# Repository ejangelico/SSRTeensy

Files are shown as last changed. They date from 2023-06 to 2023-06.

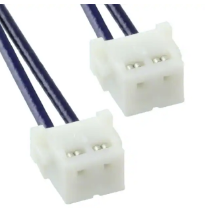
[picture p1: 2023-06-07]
widaq-magis-ssr-v2b/v2a-power-board/box-assembly/Screenshot 2023-04-20 at 11.49.00 AM.png

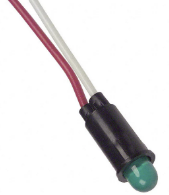
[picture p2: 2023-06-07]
widaq-magis-ssr-v2b/v2a-power-board/box-assembly/Screenshot 2023-04-20 at 11.48.34 AM.png

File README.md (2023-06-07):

# SSRTeensy

## Libraries
Arduino 1.8.15
Teensydino 1.54

# Communication interface guide (documentation in progress)

There are 16 pulse width modulation (PWM) channels active and available for functions related to setting the temperature of heaters using solid state relays and thermocouple feedback. Each of the channels initializes an "SSRController" object. The object contains a state enumerator for the presently active function of the channel. This section describes how to interface with each channel by sending messages over a serial connection. 

### Available commands

The general structure of a message to the Teensy is in the following form: `#<ch>:<command>=<arg1>,<arg2>,<arg3>,<arg4>,<arg5>` . 

Depending on the command type, there may be a different number of required arguments, and argument parsing stops once the required arguments are parsed. Commands are their arguments are described in the below list. 

- TEMP_SET : command subset for changing the SSR duty cycles to match a setpoint temperature or manual input
    - POWER_OFF : turn SSR relays to 0 duty cycle
        - `#3:TEMP_SET=POWER_OFF,,,`
    - RAMP : linear ramp in temperature up to a setpoint
    - CONST : reach a constant temperature (with no controlled slope ramp) and hold at that temperature
    - MANUAL : manually set the duty cycle of SSRs to some fraction from 0% to 100%
        - `#3:TEMP_SET=MANUAL,<duty cycle 0 to 100>,,,`, `#3:TEMP_SET=MANUAL,43.5,,,`
- TEMP_CUR : provide the Teenys with information about the present temperature associated with a particular SSR channel; this is feedback for a PID loop or any of the TEMP_SET functions
    - `#<ch>:TEMP_CUR=<temp in C>,<timestamp>`, `#3:TEMP_CUR=32.5,1656444270`
- PIDP_SET : set the P, I, and D parameters for the PID control equation

# To do for devs
- We want to change the ramp functionality inputs so that the UI just presses "start" or "stop" and the linear ramp curve is executed automatically (no timing arguments). Target temp and ramp rate are still args, but even ramp rate can have a default of 1 C/min.

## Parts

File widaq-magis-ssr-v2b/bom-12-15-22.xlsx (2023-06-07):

ID | # per board | spare per board | cost per part | number of boards | total required | total cost | component label | component type | value | vendor | product number | link | Note | Checked for correctness
1 | 4 | 0 | 19.95 | 6 | 24 | 478.8 | Teen1 | Teensy 4.0 | Teensy4 | SparkFun | DEV-16771 | here (https://www.pjrc.com/store/teensy40.html)
2 | 8 | 0 | 0.82 | 6 | 48 | 39.36 | Teen1-sockets | 14 Pin female header |  | Digikey | S7012-ND | here | soldered to pcb
3 | 16 | 2 | 0.44 | 6 | 108 | 47.52 | BUF_0-3, BUF_4-7, BUF_8-11, BUF_12-15 | IC buffer 5.5 14-DIP package | SN74AHCT125 | Digikey | 296-4655-5-ND | here (https://www.digikey.com/en/products/detail/texas-instruments/sn74ahct125n/375798)
4 | 16 | 0 | 0.21 | 6 | 96 | 20.16 | BUF_0-3, BUF_4-7, BUF_8-11, BUF_12-15 | Socket for 14-DIP IC | A14-LC-TT | Digikey | AE9989-ND | here (https://www.digikey.com/en/products/detail/assmann-wsw-components/a-14-lc-tt/821743)
5 | 5 | 1 | 3.24 | 3 | 18 |  |  | Panel mount LEDs, built in resistor |  | Digikey |  | here (https://www.digikey.com/en/products/detail/visual-communications-company---vcc/5102H5-5V/59913)
6 | 2 | 1 | 0.09 | 6 | 18 | 1.62 | R3,R4 | Resistor | 10k | Digikey | CF18JT10K0CT-ND | here (https://www.digikey.com/en/products/detail/stackpole-electronics-inc/CF18JT10K0/1741566)
7 | 1 | 1 | 0.09 | 6 | 12 | 1.08 | R1 | Resistor | 1k | Digikey | CF14JT1K00CT-ND | here (https://www.digikey.com/product-detail/en/stackpole-electronics-inc/CF14JT1K00/CF14JT1K00CT-ND/1830350)
8 | 1 | 1 | 0.09 | 6 | 12 | 1.08 | R2 | Resistor | 2k | Digikey | CF14JT2K00CT-ND | here (https://www.digikey.com/product-detail/en/stackpole-electronics-inc/CF14JT2K00/CF14JT2K00CT-ND/1830357)
9 | 2 |  |  | 3 | 6 |  |  | Switches for front panel |  | Digikey |  | here (https://www.digikey.com/en/products/detail/zf-electronics/SRB22A2FBBNN/446021)
10 | 1 |  |  | 3 | 3 |  |  | Button for front panel |  | Digikey |  | here (https://www.digikey.com/en/products/detail/switchcraft-inc./903X/1832324)
11 | 4 | 0 | 3.81 | 6 | 24 |  |  | Ribbon cable PCB receptacle, 34 pin |  | Digikey | A33169-ND | here (https://www.digikey.com/en/products/detail/te-connectivity-amp-connectors/5103309-7/1114907)
12 | 4 | 1 | 2.75 | 6 | 30 |  |  | Ribbon cable connector, free 34 pin |  | Digikey | ASC34H-ND | here (https://www.digikey.com/en/products/detail/te-connectivity-amp-connectors/1658620-8/825431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)
13 | 4 | 0 |  | 6 | 24 |  |  | DSUB-37 to ribbon |  | Digikey | HMU37H-ND | here (https://www.digikey.com/en/products/detail/assmann-wsw-components/A-DSF-37LPIII-Z-UNC/924313)
14 | 4 | 1 | 0.85 | 3 | 15 |  |  | USB-C jack |  | Digikey | 2169900003 | here (https://www.digikey.com/en/products/detail/molex/2169900003/13913753)
15 | 1 | 1 | 2 | 3 | 6 |  |  | Ribbon connection cable between RPi and Power board |  | Adafruit | 370 | here (https://www.adafruit.com/product/370)
16 | 1 | 1 | 0.21 | 3 | 6 |  |  | 2x5 pin header soldered in power board |  | Digikey |  | here (https://www.digikey.com/en/products/detail/adam-tech/PH2-12-UA/9830397)
17 | 4 | 1 | 0.16 | 3 | 15 |  |  | 2-pin JST header for LED cable |  | Digikey |  | here (https://www.digikey.com/en/products/detail/jst-sales-america-inc./S2B-PH-K-SLFSN/926626)
18 | 4 | 1 | 1.07 | 3 | 15 |  |  | 2-pin cable for LEDs |  | Digikey |  | here (https://www.digikey.com/en/products/detail/jst-sales-america-inc/A02KR02KR26E305B/6194809)
 |  |  |  |  | Cost per board | Overall total
 |  |  |  |  | 98.27 | 589.62
 |  |  |  |  |  |  |  | Please order, as of 12-15-2022, where BOM is still in progress

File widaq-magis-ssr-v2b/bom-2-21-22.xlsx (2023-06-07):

ID | # per board | spare per board | cost per part | number of boards | total required | total cost | component label | component type | value | vendor | product number | link | Note | Checked for correctness
1 | 1 | 0 | 19.95 | 2 | 2 | 39.9 | Teen1 | Teensy 4.0 | Teensy4 | SparkFun | DEV-16771 | here (https://www.pjrc.com/store/teensy40.html) |  | 2022-02-21
2 | 1 | 0 | 0.41 | 2 | 2 | 0.82 | HC1 | 4 pin female header |  | Digikey | S7002-ND | here (https://www.digikey.com/en/products/detail/sullins-connector-solutions/PPTC041LFBN-RC/810144) | for hc06 socket | 2022-02-21
3 | 2 | 0 | 0.82 | 2 | 4 | 3.28 | Teen1-sockets | 14 Pin female header |  | Digikey | S7012-ND | here (https://www.digikey.com/products/en?keywords=PPTC141LFBN-RC) | soldered to pcb | 2022-02-21
4 | 1 | 0 | 12.3 | 2 | 2 | 24.6 | PS1 | AC-DC converter | IRM-20-5 | Digikey | 1866-3042-ND | here (https://www.digikey.com/en/products/detail/mean-well-usa-inc/IRM-20-5/7704667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) |  | 2022-02-21
5 | 4 | 1 | 0.54 | 2 | 10 | 5.4 | BUF_0-3, BUF_4-7, BUF_8-11, BUF_12-15 | IC buffer 5.5 14-DIP package | SN74AHCT125 | Digikey | 296-4655-5-ND | here (https://www.digikey.com/en/products/detail/texas-instruments/SN74AHCT125N/375798) |  | 2022-02-21
6 | 4 | 0 | 0.21 | 2 | 8 | 1.68 | BUF_0-3, BUF_4-7, BUF_8-11, BUF_12-15 | Socket for 14-DIP IC | A14-LC-TT | Digikey | AE9989-ND | here (https://www.digikey.com/en/products/detail/assmann-wsw-components/A-14-LC-TT/821743) |  | 2022-02-21
7 | 1 | 0 | 8.49 | 2 | 2 | 16.98 | HC06 | HC06 | HC06 | Amazon or other |  | here (https://www.amazon.com/DSD-TECH-Wireless-Bluetooth-Transceiver/dp/B01FCQZ8VW) |  | 2022-02-21
8 | 1 | 0 | 0.86 | 2 | 2 | 1.72 | S1 | Small 1 pole switch | 1825255-1 | Digikey | 450-1567-ND | here (https://www.digikey.com/en/products/detail/te-connectivity-alcoswitch-switches/1825255-1/1202278) |  | 2022-02-21
9 | 1 | 1 | 0.19 | 2 | 4 | 0.76 | D1 | 5.1V zener diode | 5.1V Zener | Digikey | TZX5V1B-TAPGICT-ND | here (https://www.digikey.com/en/products/detail/vishay-general-semiconductor-diodes-division/TZX5V1B-TAP/8564604) |  | 2022-02-21
10 | 1 | 1 | 0.28 | 2 | 4 | 1.12 | C4 | Capacitor | 0.01 uF | Digikey | 445-173587-1-ND | here (https://www.digikey.com/en/products/detail/tdk-corporation/FG28X7R1H103KNT06/5812192) |  | 2022-02-21
11 | 1 | 1 | 0.23 | 2 | 4 | 0.92 | C3 | Capacitor | 0.1uF | Digikey | 445-173588-1-ND | here (https://www.digikey.com/en/products/detail/tdk-corporation/FG28X7R1H104KNT06/5812193) |  | 2022-02-21
12 | 2 | 1 | 0.38 | 2 | 6 | 2.28 | C1,C2 | Capacitor | 1uF | Digikey | 445-173583-1-CT | here (https://www.digikey.com/en/products/detail/tdk-corporation/FG28X7R1E105KRT06/5812188) |  | 2022-02-21
13 | 2 | 1 | 0.09 | 2 | 6 | 0.54 | R3,R4 | Resistor | 10k | Digikey | CF18JT10K0CT-ND | here (https://www.digikey.com/en/products/detail/stackpole-electronics-inc/CF18JT10K0/1741566) |  | 2022-02-21
14 | 1 | 1 | 0.09 | 2 | 4 | 0.36 | R1 | Resistor | 1k | Digikey | CF14JT1K00CT-ND | here (https://www.digikey.com/product-detail/en/stackpole-electronics-inc/CF14JT1K00/CF14JT1K00CT-ND/1830350) |  | 2022-02-21
15 | 1 | 1 | 0.09 | 2 | 4 | 0.36 | R2 | Resistor | 2k | Digikey | CF14JT2K00CT-ND | here (https://www.digikey.com/product-detail/en/stackpole-electronics-inc/CF14JT2K00/CF14JT2K00CT-ND/1830357) |  | 2022-02-21
16 | 1 | 0 | 2.35 | 2 | 2 | 4.7 | not on board | 3-pin AC power input jack |  | Digikey | Q201-ND | here (https://www.digikey.com/en/products/detail/qualtek/719W-00%2F02/245542) | with fuse box | 2022-02-21
17 | 2 | 0 | 10.63 | 2 | 4 | 42.52 | T1, T2 | 16 position terminal block, 2 rows | EELK | Digikey | 2861-EELK508V-16P-ND | here (https://www.digikey.com/en/products/detail/dinkle-corporation-usa/EELK508V-16P/15222244) |  | 2022-02-21
18 | 3 | 3 | 0.48 | 2 | 12 | 5.76 | not on board | Plug crimp pins |  | Digikey | WM14175CT-ND | here (https://www.digikey.com/en/products/detail/molex/0039000139/3160075) | crimps for power | 2022-02-21
19 | 1 | 0 | 0.35 | 2 | 2 | 0.7 | not on board | Power input plug 3pin |  | Digikey | WM18434-ND | here (https://www.digikey.com/en/products/detail/molex/0039014030/300067) |  | 2022-02-21
20 | 1 | 0 | 1.36 | 2 | 2 | 2.72 | PJ1 | power input jack 3 pin | 39303037 | Digikey | WM23935-ND | here (https://www.digikey.com/en/products/detail/molex/0039303037/930347) |  | 2022-02-21
21 | 4 | 2 | 0.32 | 2 | 12 | 3.84 | FS1, FS2 | Fuse mounting sockets for heater lines | 6021-0-15-80-16-27-10-0 | Digikey | ED90445-ND | here (https://www.digikey.com/en/products/detail/mill-max-manufacturing-corp/6021-0-15-80-16-27-10-0/2236859) |  | 2022-02-21
22 | 2 | 2 | 0.95 | 2 | 8 | 7.6 | inserted into sockets | Axial on-board 1A fuses | 251001 | Digikey | F3169CT-ND | here (https://www.digikey.com/en/products/detail/littelfuse-inc/0251001-MRT1L/700720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) |  | 2022-02-21
 |  |  |  |  | Cost per board | Overall total
 |  |  |  |  | 84.28 | 168.56

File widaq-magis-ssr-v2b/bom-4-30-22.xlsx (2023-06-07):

ID | # per board | spare per board | cost per part | number of boards | total required | total cost | component label | component type | value | vendor | product number | link | Note | Checked for correctness
1 | 4 | 0 | 19.95 | 2 | 8 | 159.6 | Teen1 | Teensy 4.0 | Teensy4 | SparkFun | DEV-16771 | here (https://www.pjrc.com/store/teensy40.html) |  | 2022-02-21
2 | 1 | 0 | 0.41 | 2 | 2 | 0.82 | HC1 | 4 pin female header |  | Digikey | S7002-ND | here (https://www.digikey.com/en/products/detail/sullins-connector-solutions/PPTC041LFBN-RC/810144) | for hc06 socket | 2022-02-21
3 | 2 | 0 | 0.82 | 2 | 4 | 3.28 | Teen1-sockets | 14 Pin female header |  | Digikey | S7012-ND | here | soldered to pcb | 2022-02-21
 |  |  |  |  |  |  |  |  |  |  |  |  |  | 2022-02-21
5 | 4 | 1 | 0.54 | 2 | 10 | 5.4 | BUF_0-3, BUF_4-7, BUF_8-11, BUF_12-15 | IC buffer 5.5 14-DIP package | SN74AHCT125 | Digikey | 296-4655-5-ND | here |  | 2022-02-21
6 | 4 | 0 | 0.21 | 2 | 8 | 1.68 | BUF_0-3, BUF_4-7, BUF_8-11, BUF_12-15 | Socket for 14-DIP IC | A14-LC-TT | Digikey | AE9989-ND | here |  | 2022-02-21
 |  |  |  |  |  |  |  |  |  |  |  |  |  | 2022-02-21
 |  |  |  |  |  |  |  |  |  |  |  |  |  | 2022-02-21
 |  |  | 3.24 |  |  |  |  | Panel mount LEDs, built in resistor |  | Digikey |  | here (https://www.digikey.com/en/products/detail/visual-communications-company---vcc/5102H5-5V/59913) |  | 2022-02-21
 |  |  |  |  |  |  |  |  |  |  |  |  |  | 2022-02-21
 |  |  |  |  |  |  |  |  |  |  |  |  |  | 2022-02-21
 |  |  |  |  |  |  |  |  |  |  |  |  |  | 2022-02-21
5 | 2 | 1 | 0.09 | 2 | 6 | 0.54 | R3,R4 | Resistor | 10k | Digikey | CF18JT10K0CT-ND | here (https://www.digikey.com/en/products/detail/stackpole-electronics-inc/CF18JT10K0/1741566) |  | 2022-02-21
6 | 1 | 1 | 0.09 | 2 | 4 | 0.36 | R1 | Resistor | 1k | Digikey | CF14JT1K00CT-ND | here (https://www.digikey.com/product-detail/en/stackpole-electronics-inc/CF14JT1K00/CF14JT1K00CT-ND/1830350) |  | 2022-02-21
7 | 1 | 1 | 0.09 | 2 | 4 | 0.36 | R2 | Resistor | 2k | Digikey | CF14JT2K00CT-ND | here (https://www.digikey.com/product-detail/en/stackpole-electronics-inc/CF14JT2K00/CF14JT2K00CT-ND/1830357) |  | 2022-02-21
 |  |  |  |  |  |  |  |  |  |  |  |  | with fuse box | 2022-02-21
9 | 2 | 0 | 10.63 | 2 | 4 | 42.52 | T1, T2 | 16 position terminal block, 2 rows | EELK | Digikey | 2861-EELK508V-16P-ND | here (https://www.digikey.com/en/products/detail/dinkle-corporation-usa/EELK508V-16P/15222244) |  | 2022-02-21
 |  |  |  |  |  |  |  |  |  |  |  |  | crimps for power | 2022-02-21
 |  |  |  |  |  |  |  | Resistor network | 4.7k | Digikey |  | here (https://www.digikey.com/en/products/detail/bourns-inc/4607X-101-472LF/2565646) |  | 2022-02-21
 |  |  |  |  |  |  |  |  |  |  |  |  |  | 2022-02-21
 |  |  |  |  |  |  |  | Switches for front panel |  | Digikey |  | here (https://www.digikey.com/en/products/detail/zf-electronics/SRB22A2FBBNN/446021) |  | 2022-02-21
 |  |  |  |  |  |  |  | Button for front panel |  | Digikey |  | here (https://www.digikey.com/en/products/detail/switchcraft-inc./903X/1832324) |  | 2022-02-21
 |  |  | 3.81 |  |  |  |  | Ribbon cable PCB receptacle, 34 pin |  | Digikey | A33169-ND | here (https://www.digikey.com/en/products/detail/te-connectivity-amp-connectors/5103309-7/1114907) |  | 2022-05-08
 |  |  | 2.75 |  |  |  |  | Ribbon cable connector, free 34 pin |  | Digikey | ASC34H-ND | here (https://www.digikey.com/en/products/detail/te-connectivity-amp-connectors/1658620-8/825431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)
 |  |  |  |  |  |  |  | Ribbon cable 37 |  | Digikey | AE37G-300-ND | here (https://www.digikey.com/en/products/detail/assmann-wsw-components/AWG28-37-G-300/655762) | will peel back 3 wires and trim in order to mate with the 34pin standard of ribbon on PCB mount
 |  |  |  |  |  |  |  | DSUB-37 to ribbon |  | Digikey | HMU37H-ND | here (https://www.digikey.com/en/products/detail/assmann-wsw-components/A-DSF-37LPIII-Z-UNC/924313)
 |  |  | 0.85 |  |  |  |  | USB-C jack |  | Digikey | 2169900003 | here (https://www.digikey.com/en/products/detail/molex/2169900003/13913753)
 |  |  | 2 |  |  |  |  | Ribbon connection cable between RPi and Power board |  | Adafruit | 370 | here (https://www.adafruit.com/product/370)
 |  |  | 0.21 |  |  |  |  | 2x5 pin header soldered in power board |  | Digikey |  | here (https://www.digikey.com/en/products/detail/adam-tech/PH2-12-UA/9830397)
 |  |  |  |  |  |  |  | Panel mount LEDs, built in resistor |  | Digikey |  | here (https://www.digikey.com/en/products/detail/visual-communications-company---vcc/5102H5-5V/59913)
 |  |  | 0.16 |  |  |  |  | 2-pin JST header for LED cable |  | Digikey |  | here (https://www.digikey.com/en/products/detail/jst-sales-america-inc./S2B-PH-K-SLFSN/926626)
 |  |  | 1.07 |  |  |  |  | 2-pin cable for LEDs |  | Digikey |  | here (https://www.digikey.com/en/products/detail/jst-sales-america-inc/A02KR02KR26E305B/6194809)
 |  |  |  |  | Cost per board | Overall total
 |  |  |  |  | 107.28 | 214.56

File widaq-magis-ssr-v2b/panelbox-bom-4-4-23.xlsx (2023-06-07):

Inventory (1/6/23) | ID | # per board | spare per board | cost per part | number of boards | total required | total cost | component label | component type | value | vendor | product number | link | Note | Checked for correctness
 | 1 | 1 | 0 | 13.49 | 1 | 1 | 13.49 |  | USB C cable pack of 2 | 1.5 ft long | Amazon | Besgoods USB C to USBC | here (https://www.amazon.com/Besgoods-Delivery-Compatible-MacBook-Docking/dp/B08G8G976B) |  | 2023-04-04
 | 2 | 2 | 0 | 9.99 | 1 | 2 | 19.98 |  | USB C cable 1.6ft right angle | 1.6 ft | Amazon | IDSONIX Smart | here (https://www.amazon.com/dp/B09VYRM4PG?s=industrial&sp_csd=d2lkZ2V0TmFtZT1zcF9kZXRhaWw) |  | 2023-04-04
 | 3 | 8 | 1 | 1.79 | 1 | 9 | 16.11 |  | 2-pin cable for LEDs, buttons, and switches |  | Digikey | 455-3154-ND | here (https://www.digikey.com/en/products/detail/jst-sales-america-inc/A02KR02KR26E305B/6194809) |  | 2023-04-04
 | 4 | 4 | 1 | 4.92 | 1 | 5 | 24.6 |  | Panel mount LEDs, built in resistor |  | Digikey | L10025-ND | here (https://www.digikey.com/en/products/detail/visual-communications-company---vcc/5102H5-5V/59913) |  | 2023-04-04
 | 5 | 3 | 1 | 1.41 | 1 | 4 | 5.64 |  | Switches for front panel |  | Digikey | CH755-ND | here (https://www.digikey.com/en/products/detail/zf-electronics/SRB22A2FBBNN/446021) |  | 2023-04-04
 | 6 | 1 | 0 | 7.46 | 1 | 1 | 7.46 |  | Button for front panel |  | Digikey | SC1510-ND | here (https://www.digikey.com/en/products/detail/switchcraft-inc./903X/1832324) |  | 2023-04-04
 | 7 | 12 | 3 | 0.55 | 1 | 15 | 8.25 |  | 6-32 Standoffs metal |  | McMaster | 93505A442 | here (https://www.mcmaster.com/93505A442/) |  | 2023-04-04
 | 8 | 1 | 0 | 5.68 | 1 | 1 | 5.68 |  | 6-32 nuts for standoffs | pack of 100 | McMaster | 90730A007 | here (https://www.mcmaster.com/90730a007/) | *DON’T BUY if inventory is already a pack of 100*, only one nut is needed per box | 2023-04-04
 | 9 | 4 | 1 | 0.58 | 1 | 5 | 2.9 |  | Plastic 6-32 standoffs |  | McMaster | 92745A342 | here (https://www.mcmaster.com/92745A342/) |  | 2023-04-04
 | 10 | 4 | 1 | 0.57 | 1 | 5 | 2.85 |  | Plastic 4-40 standoffs |  | McMaster | 92745A322 | here (https://www.mcmaster.com/92745A322) |  | 2023-04-04
 | 11 | 1 | 0 | 10.46 | 1 | 1 | 10.46 |  | Plastic 4-40 nuts | pack of 100 | McMaster | 94812A200 | here (https://www.mcmaster.com/94812a200/) | *DON’T BUY if inventory is already a pack of 100*, only one nut is needed per box | 2023-04-04
 | 12 | 1 | 0 | 5.43 | 1 | 1 | 5.43 |  | 4-40 screws for bottom of box | pack of 100 | McMaster | 92210A105 | here (https://www.mcmaster.com/92210a105/) | *DON’T BUY if inventory is already a pack of 100*, only one nut is needed per box | 2023-04-04
 | 13 | 1 | 0 | 6.91 | 1 | 1 | 6.91 |  | 6-32 screws for bottom of box | pack of 100 | McMaster | 92210A144 | here (https://www.mcmaster.com/92210a144/) | *DON’T BUY if inventory is already a pack of 100*, only one nut is needed per box | 2023-04-04
 | 14 | 1 | 0 | 14.15 | 1 | 1 | 14.15 |  | 120VAC lamp indicator |  | Digikey | CNX722C500120T | here (https://www.digikey.com/en/products/detail/visual-communications-company-vcc/cnx722c500120t/7672109) |  | 2023-04-04
 | 15 | 1 | 0 | 8.78 | 1 | 1 | 8.78 |  | RJ45 jack bulkhead |  | Digikey | ASICPICRJ45S | here (https://www.digikey.com/en/products/detail/asi-ez/ASICPICRJ45S/14008444) |  | 2023-04-04
 | 16 | 1 | 1 | 4.28 | 1 | 2 | 8.56 |  | 0.5 ft ethernet patch cable |  | Amazon | Monoprice 0.5ft Cat6 | here (https://www.amazon.com/Monoprice-550MHz-Ethernet-Copper-Network/dp/B004C4ZRFI) |  | 2023-04-04
 | 17 | 1 | 0 | 8.99 | 1 | 1 | 8.99 |  | USB micro cable with data lines pack of 3 |  | Amazon | Rankie Micro USB 3ft | here (https://www.amazon.com/Rankie-Micro-Charging-Braided-3-Pack/dp/B01JPDTZXK) | *DON’T BUY if inventory has more than 1. Only one per box needed | 2023-04-04
 | 18 | 1 | 0 | 14.88 | 1 | 1 | 14.88 |  | 120VAC input, switched, fused, UL |  | RS-Online | 4304.6058 | here (https://us.rs-online.com/product/schurter/4304-6058/70434907/?referrer=search) |  | 2023-04-04
 | 19 | 1 | 1 | 1.06 | 1 | 2 | 2.12 |  | Fuse for AC input, 10A 250VAC fastblow |  | Digikey | 0217010.MXBP | here (https://www.digikey.com/en/products/detail/littelfuse-inc./0217010.MXBP/3425452) |  | 2023-04-04
 | 20 | 16 | 4 | 0.96 | 1 | 20 | 19.2 |  | Small 4-40 hex male to female nuts for DB37 connector mounting |  | McMaster | 93505A460 | here (https://www.mcmaster.com/93505A460/) |  | 2023-04-04
 | 21 | 5 | 2 | 0.52 | 2 | 14 | 7.28 |  | Blade terminal crimp connector for 120VAC |  | Digikey | 190020033 | here (https://www.digikey.com/en/products/detail/molex/0190020033/13562240) |  | 2023-04-04
 |  |  |  |  |  | Cost per board | Overall total
 |  |  |  |  |  | 213.72 | 213.72

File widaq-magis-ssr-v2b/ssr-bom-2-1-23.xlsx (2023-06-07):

Inventory (1/6/23) | ID | # per board | spare per board | cost per part | number of boards | total required | total cost | component label | component type | value | vendor | product number | link | Note | Checked for correctness
28 | 1 | 4 | 0 | 19.95 | 1 | 4 | 79.8 | Teen1, Teen2, Teen3, Teen4 | Teensy 4.0 | Teensy4 | SparkFun | DEV-16771 | here (https://www.pjrc.com/store/teensy40.html)
 | 2 | 8 | 0 | 0.82 | 1 | 8 | 6.56 | Teen1, Teen2, Teen3, Teen4 | 14 Pin female header |  | Digikey | S7012-ND | here | soldered to pcb
108 | 3 | 16 | 2 | 0.44 | 1 | 18 | 7.92 | BUF_0-3, BUF_4-7, BUF_8-11, BUF_12-15 | IC buffer 5.5 14-DIP package | SN74AHCT125 | Digikey | 296-4655-5-ND | here (https://www.digikey.com/en/products/detail/texas-instruments/sn74ahct125n/375798)
 | 4 | 16 | 1 | 0.21 | 1 | 17 | 3.57 | BUF_0-3, BUF_4-7, BUF_8-11, BUF_12-15 | Socket for 14-DIP IC | A14-LC-TT | Digikey | AE9989-ND | here (https://www.digikey.com/en/products/detail/assmann-wsw-components/a-14-lc-tt/821743)
24 | 5 | 4 | 0 | 3.81 | 1 | 4 | 15.24 | DSUB1, DSUB2, DSUB3, DSUB4 | Ribbon cable PCB receptacle, 34 pin |  | Digikey | A33169-ND | here (https://www.digikey.com/en/products/detail/te-connectivity-amp-connectors/5103309-7/1114907)
30 | 6 | 4 | 1 | 2.75 | 1 | 5 | 13.75 | not on board | Ribbon cable connector, free 34 pin |  | Digikey | ASC34H-ND | here (https://www.digikey.com/en/products/detail/te-connectivity-amp-connectors/1658620-8/825431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)
24 | 7 | 4 | 0 | 3.85 | 1 | 4 | 15.4 | not on board | DSUB-37 to ribbon |  | Digikey | HMU37H-ND | here (https://www.digikey.com/en/products/detail/assmann-wsw-components/A-DSF-37LPIII-Z-UNC/924313)
15 | 8 | 1 | 1 | 0.85 | 1 | 2 | 1.7 | J1 | USB-C jack |  | Digikey | 2169900003 | here (https://www.digikey.com/en/products/detail/molex/2169900003/13913753)
 | 9 | 3 | 1 | 0.16 | 1 | 4 | 0.64 | SW1, SW2, D1 | 2-pin JST header for LED cable |  | Digikey |  | here (https://www.digikey.com/en/products/detail/jst-sales-america-inc./S2B-PH-K-SLFSN/926626)
 | 10 | 3 | 1 | 1.07 | 1 | 4 | 4.28 | not on board | 2-pin cable for LEDs |  | Digikey |  | here (https://www.digikey.com/en/products/detail/jst-sales-america-inc/A02KR02KR26E305B/6194809)
 | 11 | 0 | 0 | 0 | 1 | 0 | 0 | R1 | Populate with wire | 0 ohm
 | 12 | 1 | 1 | 0.96 | 1 | 2 | 1.92 | F2 | 2A Little Fuse |  | Digikey | F3171CT-ND | here (https://www.digikey.com/en/products/detail/littelfuse-inc/0251002-MRT1L/700731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)
 | 13 | 2 | 2 | 0.8 | 1 | 4 | 3.2 | F2 | Fuse sockets soldered into fuse vias |  | Digikey | A24856-ND | here (https://www.digikey.com/en/products/detail/te-connectivity-amp-connectors/2-331272-6/292008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)
 | 14 | 1 | 1 | 0.74 | 1 | 2 | 1.48 | C2 | Capacitor | 1uF | Digikey | 495-2470-1-ND | here (https://www.digikey.com/en/products/detail/epcos-tdk-electronics/B32529C0105K189/1089751)
 | 15 | 1 | 1 | 0.47 | 1 | 2 | 0.94 | C3 | Capacitor | 100 nF | Digikey | ECQ-E4104KF3 | here (https://www.digikey.com/en/products/detail/panasonic-electronic-components/ECQ-E4104KF3/2579183)
 | 16 | 1 | 1 | 0.48 | 1 | 2 | 0.96 | C4 | Capacitor | 10 nF | Digikey | ECQ-6103KF3 | here (https://www.digikey.com/en/products/detail/panasonic-electronic-components/ECQ-E6103KF3/2579152)
 | 17 | 4 | 1 | 0.53 | 1 | 5 | 2.65 | C1, C5, C6, C7 | Capacitor | 1 nF | Digikey | ECQ-E6102KF3 | here (https://www.digikey.com/en/products/detail/panasonic-electronic-components/ECQ-E6102KF3/14113886)
 | 18 | 1 | 1 | 0.06 | 1 | 2 | 0.12 | JP1 | 2 pin .1" header |  | Digikey | S1012EC-02-ND | here (https://www.digikey.com/en/products/detail/sullins-connector-solutions/PREC002SAAN-RC/2774852)
 | 19 | 1 | 1 | 0.1 | 1 | 2 | 0.2 | Not on board | Jumpers | 0.1" | Digikey | S9337-ND | here (https://www.digikey.com/en/products/detail/sullins-connector-solutions/QPC02SXGN-RC/2618262)
 |  |  |  |  |  |  |  | HC1, HC2, HC3, HC4 | HC06 bluetooth modules | Do not populate or order
 |  |  |  |  |  |  |  | R3, R4, R5, R6, R7, R8, R9, R10 | Resistors, 1k and 2k | Do not populate or order
 |  |  |  |  |  | Cost per board | Overall total
 |  |  |  |  |  | 160.33 | 160.33

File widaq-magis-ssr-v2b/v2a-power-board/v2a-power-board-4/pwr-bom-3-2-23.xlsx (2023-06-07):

Inventory (1/6/23) | ID | # per board | spare per board | cost per part | number of boards | total required | total cost | component label | component type | value | vendor | product number | link | Note | Checked for correctness
15 | 1 | 2 | 1 | 0.85 | 1 | 3 | 2.55 | J1, J2 | USB-C jack |  | Digikey | 2169900003 | here (https://www.digikey.com/en/products/detail/molex/2169900003/13913753)
 | 2 | 1 | 1 | 2 | 1 | 2 | 4 | not on board | Ribbon connection cable between RPi and Power board |  | Adafruit | 370 | here (https://www.adafruit.com/product/370)
 | 3 | 1 | 1 | 0.21 | 1 | 2 | 0.42 | J3 | 2x5 pin header soldered in power board |  | Digikey |  | here (https://www.digikey.com/en/products/detail/adam-tech/PH2-12-UA/9830397)
 | 4 | 4 | 1 | 0.16 | 1 | 5 | 0.8 | SW1, SW2, D1, D2 | 2-pin JST header for LED cable |  | Digikey |  | here (https://www.digikey.com/en/products/detail/jst-sales-america-inc./S2B-PH-K-SLFSN/926626)
 | 5 | 3 | 1 | 0.96 | 1 | 4 | 3.84 | F1, F2, F3 | 4A Little fuse |  | Digikey | F3173CT-ND | here (https://www.digikey.com/en/products/detail/littelfuse-inc/0251004-MRT1L/700747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)
 | 6 | 6 | 2 | 0.8 | 1 | 8 | 6.4 | F1, F2, F3 | Fuse sockets soldered into fuse vias |  | Digikey | A24856-ND | here (https://www.digikey.com/en/products/detail/te-connectivity-amp-connectors/2-331272-6/292008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)
 | 7 | 1 | 1 | 0.74 | 1 | 2 | 1.48 | C1, C2 | Capacitor | 1uF | Digikey | 495-2470-1-ND | here (https://www.digikey.com/en/products/detail/epcos-tdk-electronics/B32529C0105K189/1089751)
 | 8 | 1 | 1 | 0.47 | 1 | 2 | 0.94 | C3, C4 | Capacitor | 100 nF | Digikey | ECQ-E4104KF3 | here (https://www.digikey.com/en/products/detail/panasonic-electronic-components/ECQ-E4104KF3/2579183)
 | 9 | 1 | 1 | 0.48 | 1 | 2 | 0.96 | C5, C6 | Capacitor | 10 nF | Digikey | ECQ-6103KF3 | here (https://www.digikey.com/en/products/detail/panasonic-electronic-components/ECQ-E6103KF3/2579152)
 | 10 | 0 | 0 | 0 | 1 | 0 | 0 | R1, R2 | Wire soldered to short | 0 ohm
 | 11 | 2 | 1 | 0.16 | 1 | 3 | 0.48 | D3, D4 | 5.1 V Zener Diode |  | Digikey | BZX79C5V1-T50A | here (https://www.digikey.com/en/products/detail/onsemi/BZX79C5V1-T50A/977930)
 | 12 | 2 | 0 | 12.27 | 1 | 2 | 24.54 | PS1, PS2 | 4A 5V AC to DC power converter |  | Mouser | 709-IRM20-5 | here (https://www.mouser.com/ProductDetail/MEAN-WELL/IRM-20-5?qs=WkdRfq4wf1PtpRVy5G6J8g%3D%3D)
 | 13 | 1 | 0 | 0.78 | 1 | 1 | 0.78 | PJ1 | power plug 3-pin input |  | Digikey | 10844030 | here (https://www.digikey.com/en/products/detail/molex/0010844030/134547)
 | 14 | 1 | 1 | 0.44 | 1 | 2 | 0.88 | not on board, but to be assembed | Power jack 3-pin |  | Digikey | 50841035 | here (https://www.digikey.com/en/products/detail/molex/0050841035/3160484)
 | 15 | 3 | 3 | 0.17 | 1 | 6 | 1.02 | not on board, but to be assembed | Pins for power jack |  | Digikey | 366630001 | here (https://www.digikey.com/en/products/detail/molex/0366630001/3185328)
 | 16 | 2 | 1 | 0.06 | 1 | 3 | 0.18 | JP1, JP2 | 2 pin .1" header |  | Digikey | S1012EC-02-ND | here (https://www.digikey.com/en/products/detail/sullins-connector-solutions/PREC002SAAN-RC/2774852)
 |  |  |  |  |  | Cost per board | Overall total
 |  |  |  |  |  | 49.27 | 49.27

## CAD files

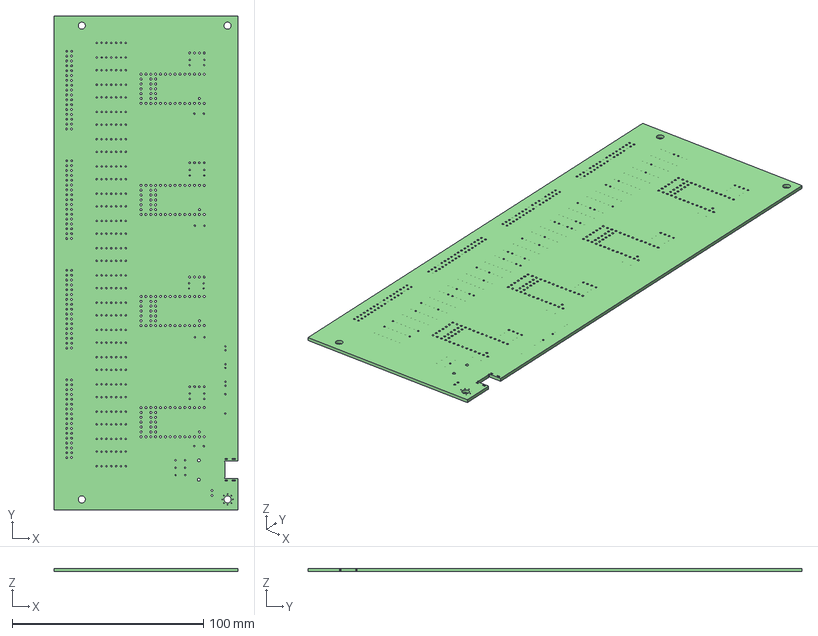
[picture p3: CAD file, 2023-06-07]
widaq-magis-ssr-v2b/output_files/2-13-23/widaq-magis-ssr-v2b.step
96.0 x 258.2 x 1.60 mm

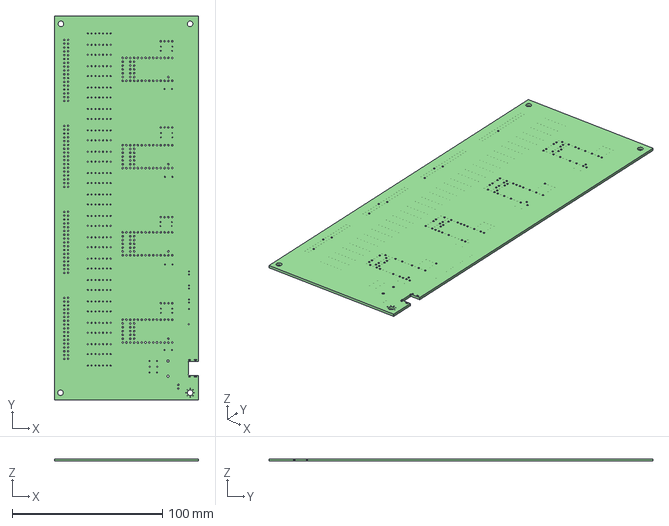
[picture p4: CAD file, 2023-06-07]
widaq-magis-ssr-v2b/output_files/widaq-magis-ssr-v2a.step
96.0 x 255.7 x 1.60 mm

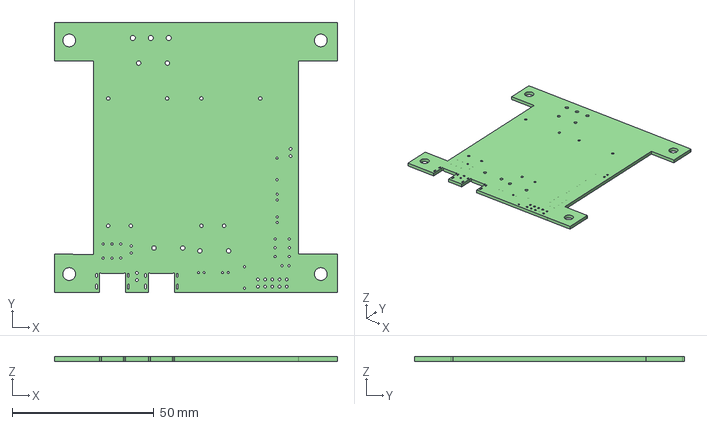
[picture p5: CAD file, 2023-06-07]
widaq-magis-ssr-v2b/v2a-power-board/v2a-power-board-4/output_files/v2a-power-board-4-a/v2a-power-board-4.step
100.0 x 95.5 x 1.60 mm

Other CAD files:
widaq-magis-ssr-v2b/output_files/2-13-23/widaq-magis-ssr-v2a.step

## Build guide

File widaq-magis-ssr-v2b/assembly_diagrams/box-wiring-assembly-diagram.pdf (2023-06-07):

RJ45 jack

Firware
restart
button

Power indicator LEDs
(left to right)
1. 5V Teensy Supply
2. 5V RPi
3. 5V Teensy Board 1
4. 5V Teensy Board 2

RPi 5V
switch

Teensy 5V
switch

SSR
output
disable

120VAC
indicator
lamp

Notes:
1. The BOM should have delivered 9x 12” two-pin JST cables like that shown above. One side sockets into the board locations shown by white rectangles on the left. The other side was intented to be cut, and soldered to the pins of their correpsonding front-panel devices such as LEDs, switches, or button. Some will be shorter than others, feel free to extend with wire if needed.
2. These connectors are polar, so please use the following diagrams to orient the wires to their correct locations on board. In some cases, polarity does not matter.
3. In the case of SSR output disable and Firmware restart button, the wires will need to split to deliver in parallel to both boards. I would suggest soldered wires and heat shrink

### Teensy Board 1

### Teensy Board 2

### Power board

### Teensy board connector wiring

### to LED red wire

to either terminal
on push button

to either terminal
on switch

### Power board, near D1 connectors

### to LED red wire

red to either terminal
of switch, (center terminal slightly prefered)

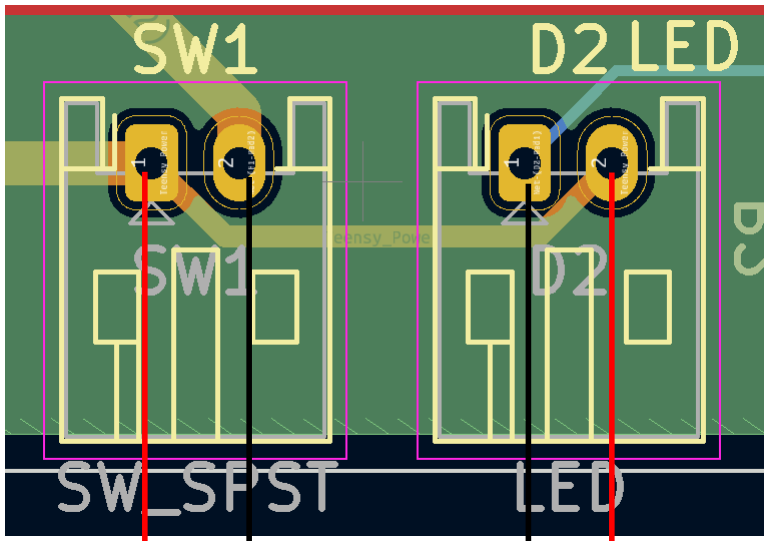
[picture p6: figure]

### to LED red wire

red to either terminal
of switch, (center terminal slightly prefered)

### Power board, near D2 connectors

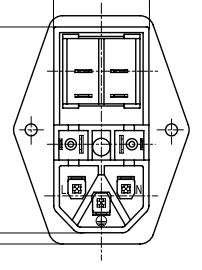
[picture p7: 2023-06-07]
widaq-magis-ssr-v2b/v2a-power-board/box-assembly/Screenshot 2023-04-19 at 4.31.22 PM.png

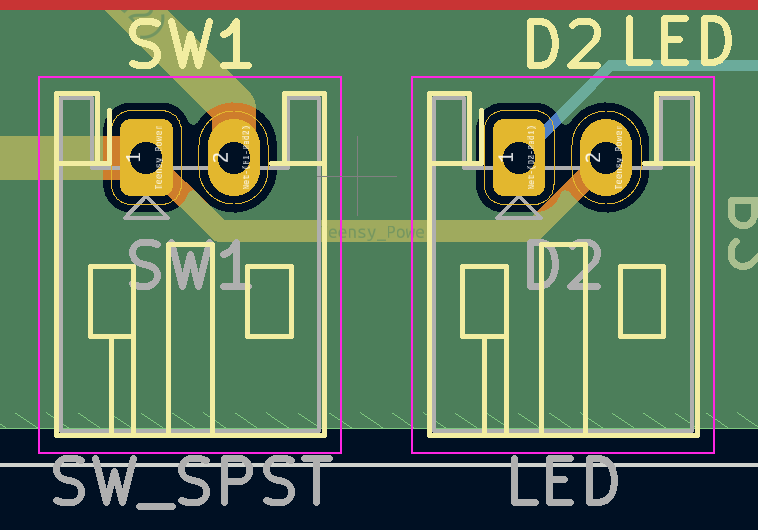
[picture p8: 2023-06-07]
widaq-magis-ssr-v2b/assembly_diagrams/Screenshot 2023-06-01 at 9.43.54 AM.png

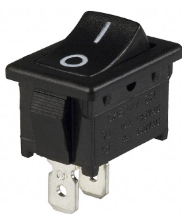
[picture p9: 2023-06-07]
widaq-magis-ssr-v2b/v2a-power-board/box-assembly/Screenshot 2023-04-20 at 11.47.38 AM.png

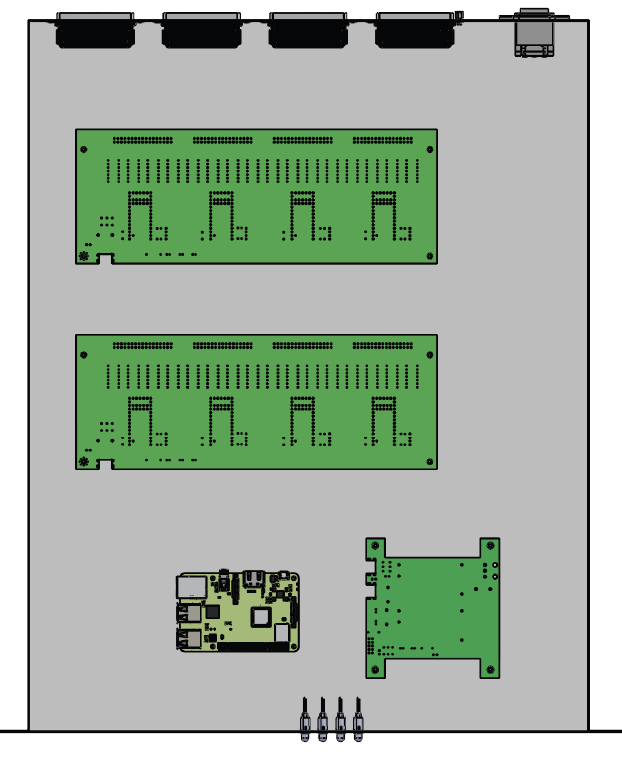
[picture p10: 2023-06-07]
widaq-magis-ssr-v2b/assembly_diagrams/topview-shot.png

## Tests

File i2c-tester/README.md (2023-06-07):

Here are some things to note about this code:

- The i2c package used is “Teensy4 I2C” which is custom but well used. Installation instructions (and the code base) can be found here: https://github.com/Richard-Gemmell/teensy4_i2c/blob/master/documentation/installation/arduino_installation.md 

- The test code in the “i2c-tester” folder has the Teensy as secondary and RPi as primary in the i2c protocol. The i2c “Wire1” object runs a function “requestEvent” when the RPi requests information. It forms a set of 16 random numbers as duty cycles representing present duty cycles of SSRs, packetizes the string and sends it to the RPi. The i2c object runs a function “receiveEvent” when it gets a message from the RPi, parsing it into a string and printing to the standard Serial readout. An end-of-message word is required, which I believe already may exist in our SSRTeensy code as well, or may be easy to implement when we integrate this scheme. 

- The node-red flow is included as a .json object for importing. It uses nodes from https://flows.nodered.org/node/node-red-contrib-i2c . It also has a loop with a sub-function that packetizes and concatenates packets into strings just like the Teensy code does. This will need to be integrated into the existing messaging scheme. 

- Wiring is as follows:
	- The ground of the RPi and the Teensy must be connector (with a wire)
	- The i2c is a 2 wire protocol: SCL (clock) and SDA (data). On the Raspberry Pi 4, this is GPIO pins labeled 3 and 5 referencing the pinout diagram attached (GPIO 2 and 3). On the Teensy 4 (and our new boards) this is pins 16 and 17. The Teensy code requires this and has a comment mentioning it. SDA goes to SDA, SCL goes to SCL between devices. 
	- If you have issues with sending messages, it may be worth trying to power both Teensy and RPi from the same 5V line in addition to them having the same ground. Though I don’t necessarily remember doing this in my test.

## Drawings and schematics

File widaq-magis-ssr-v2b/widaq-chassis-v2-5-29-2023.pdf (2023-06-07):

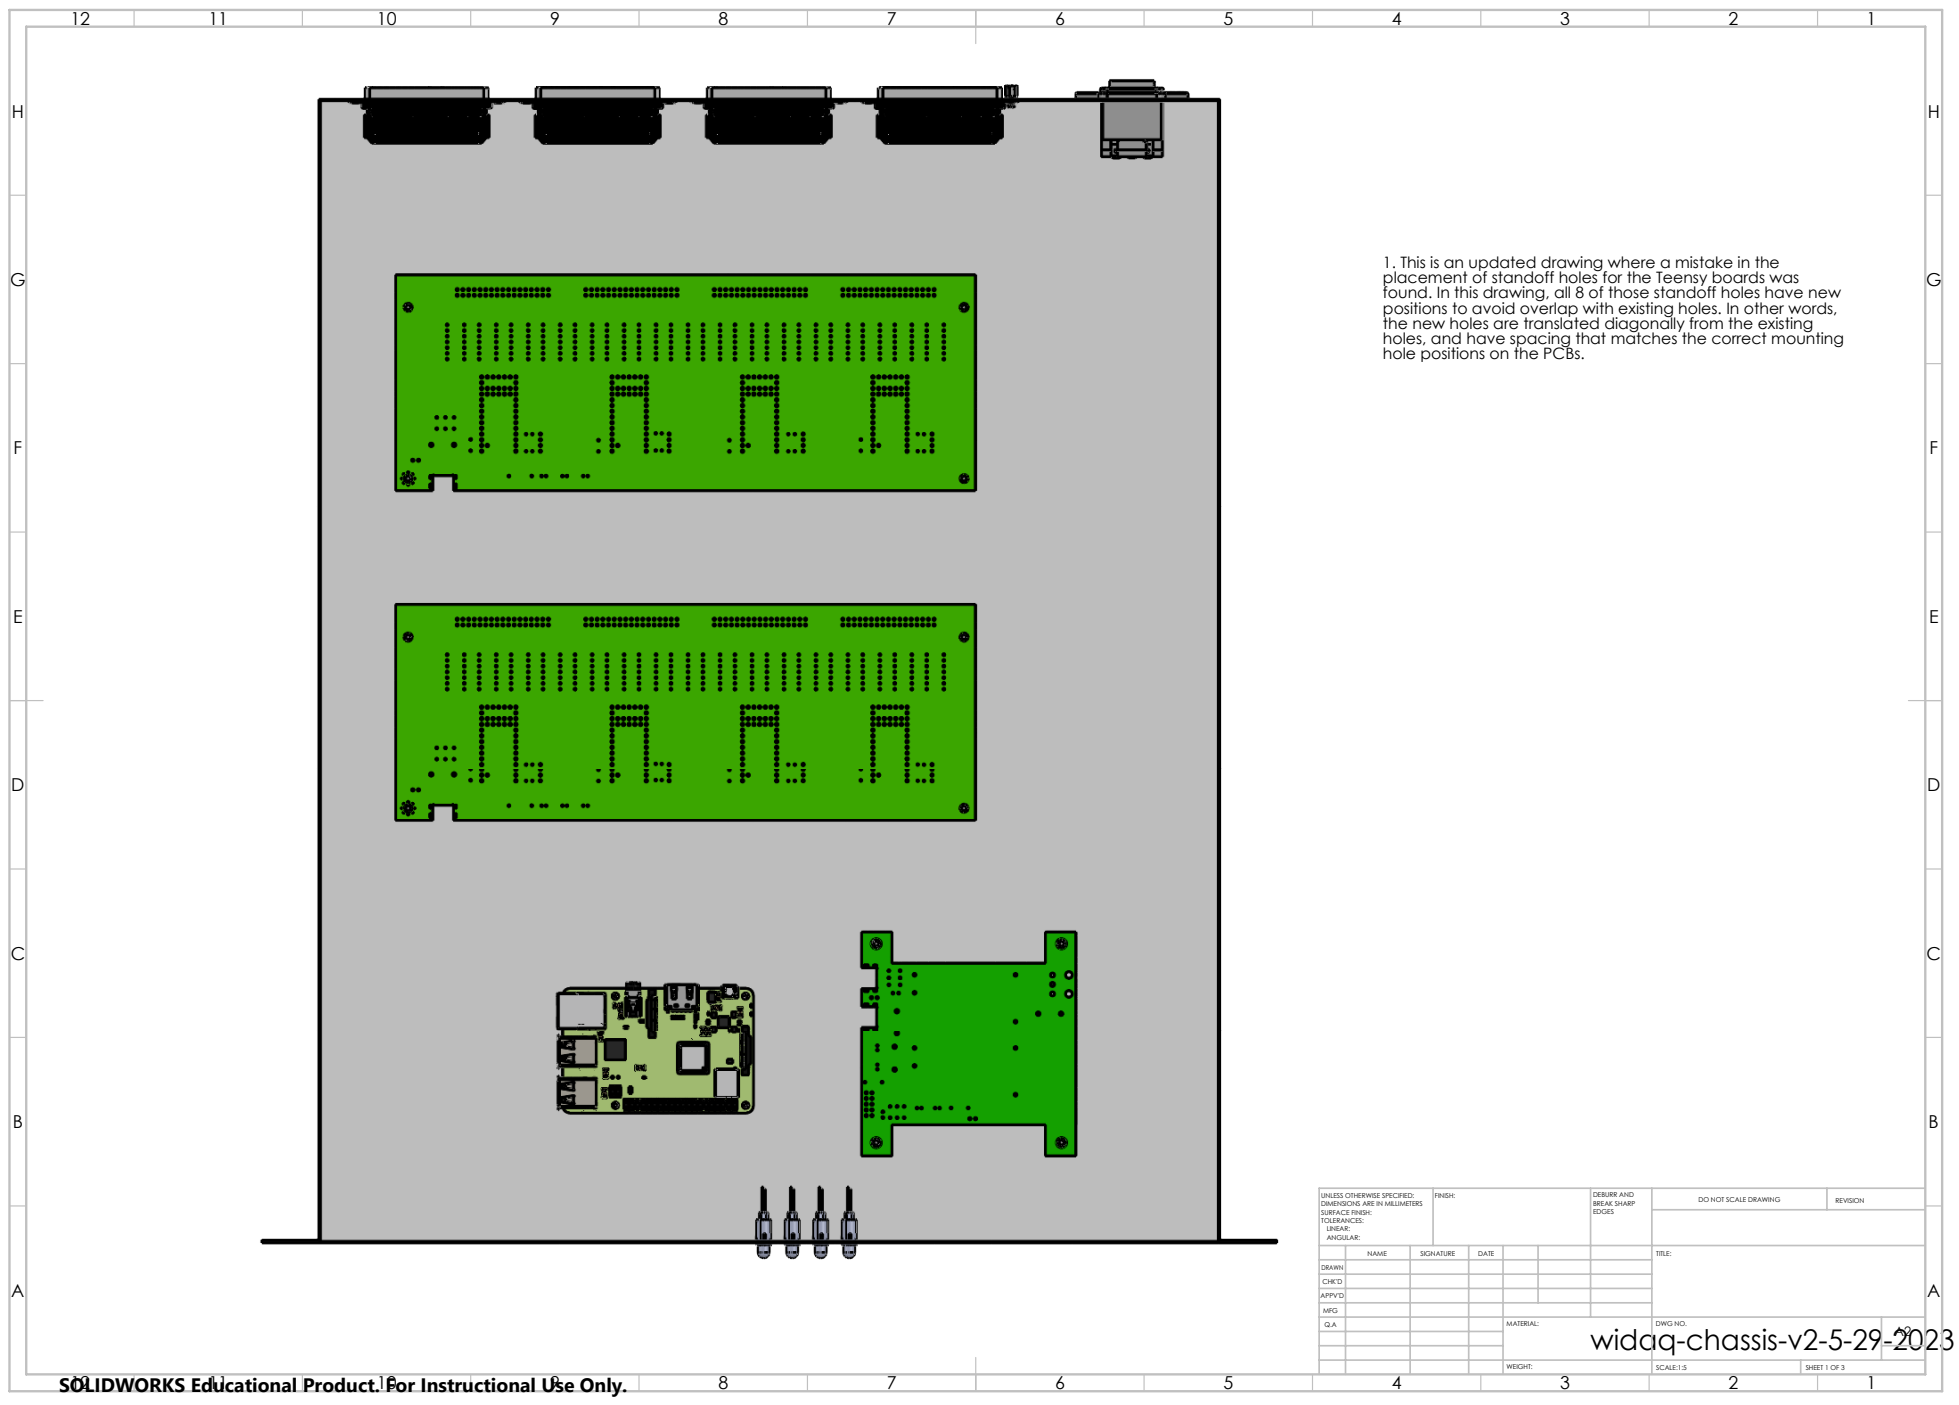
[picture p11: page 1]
SCALE:1:5; SHEET 1 OF 3

1. This is an updated drawing where a mistake in the
placement of standoff holes for the Teensy boards was
found. In this drawing, all 8 of those standoff holes have new
positions to avoid overlap with existing holes. In other words,
the new holes are translated diagonally from the existing
holes, and have spacing that matches the correct mounting
hole positions on the PCBs.

UNLESS OTHERWISE SPECIFIED: DIMENSIONS ARE IN MILLIMETERS SURFACE FINISH: TOLERANCES: LINEAR: ANGULAR: | FINISH: | DEBURR AND BREAK SHARP EDGES | DO NOT SCALE DRAWING | REVISION

NAME | SIGNATURE | DATE | | | | TITLE:

DRAWN
CHK'D
APPV'D
MFG
Q.A | | | | MATERIAL: | DWG NO. | A2

SOLIDWORKS Educational Product. For Instructional Use Only.

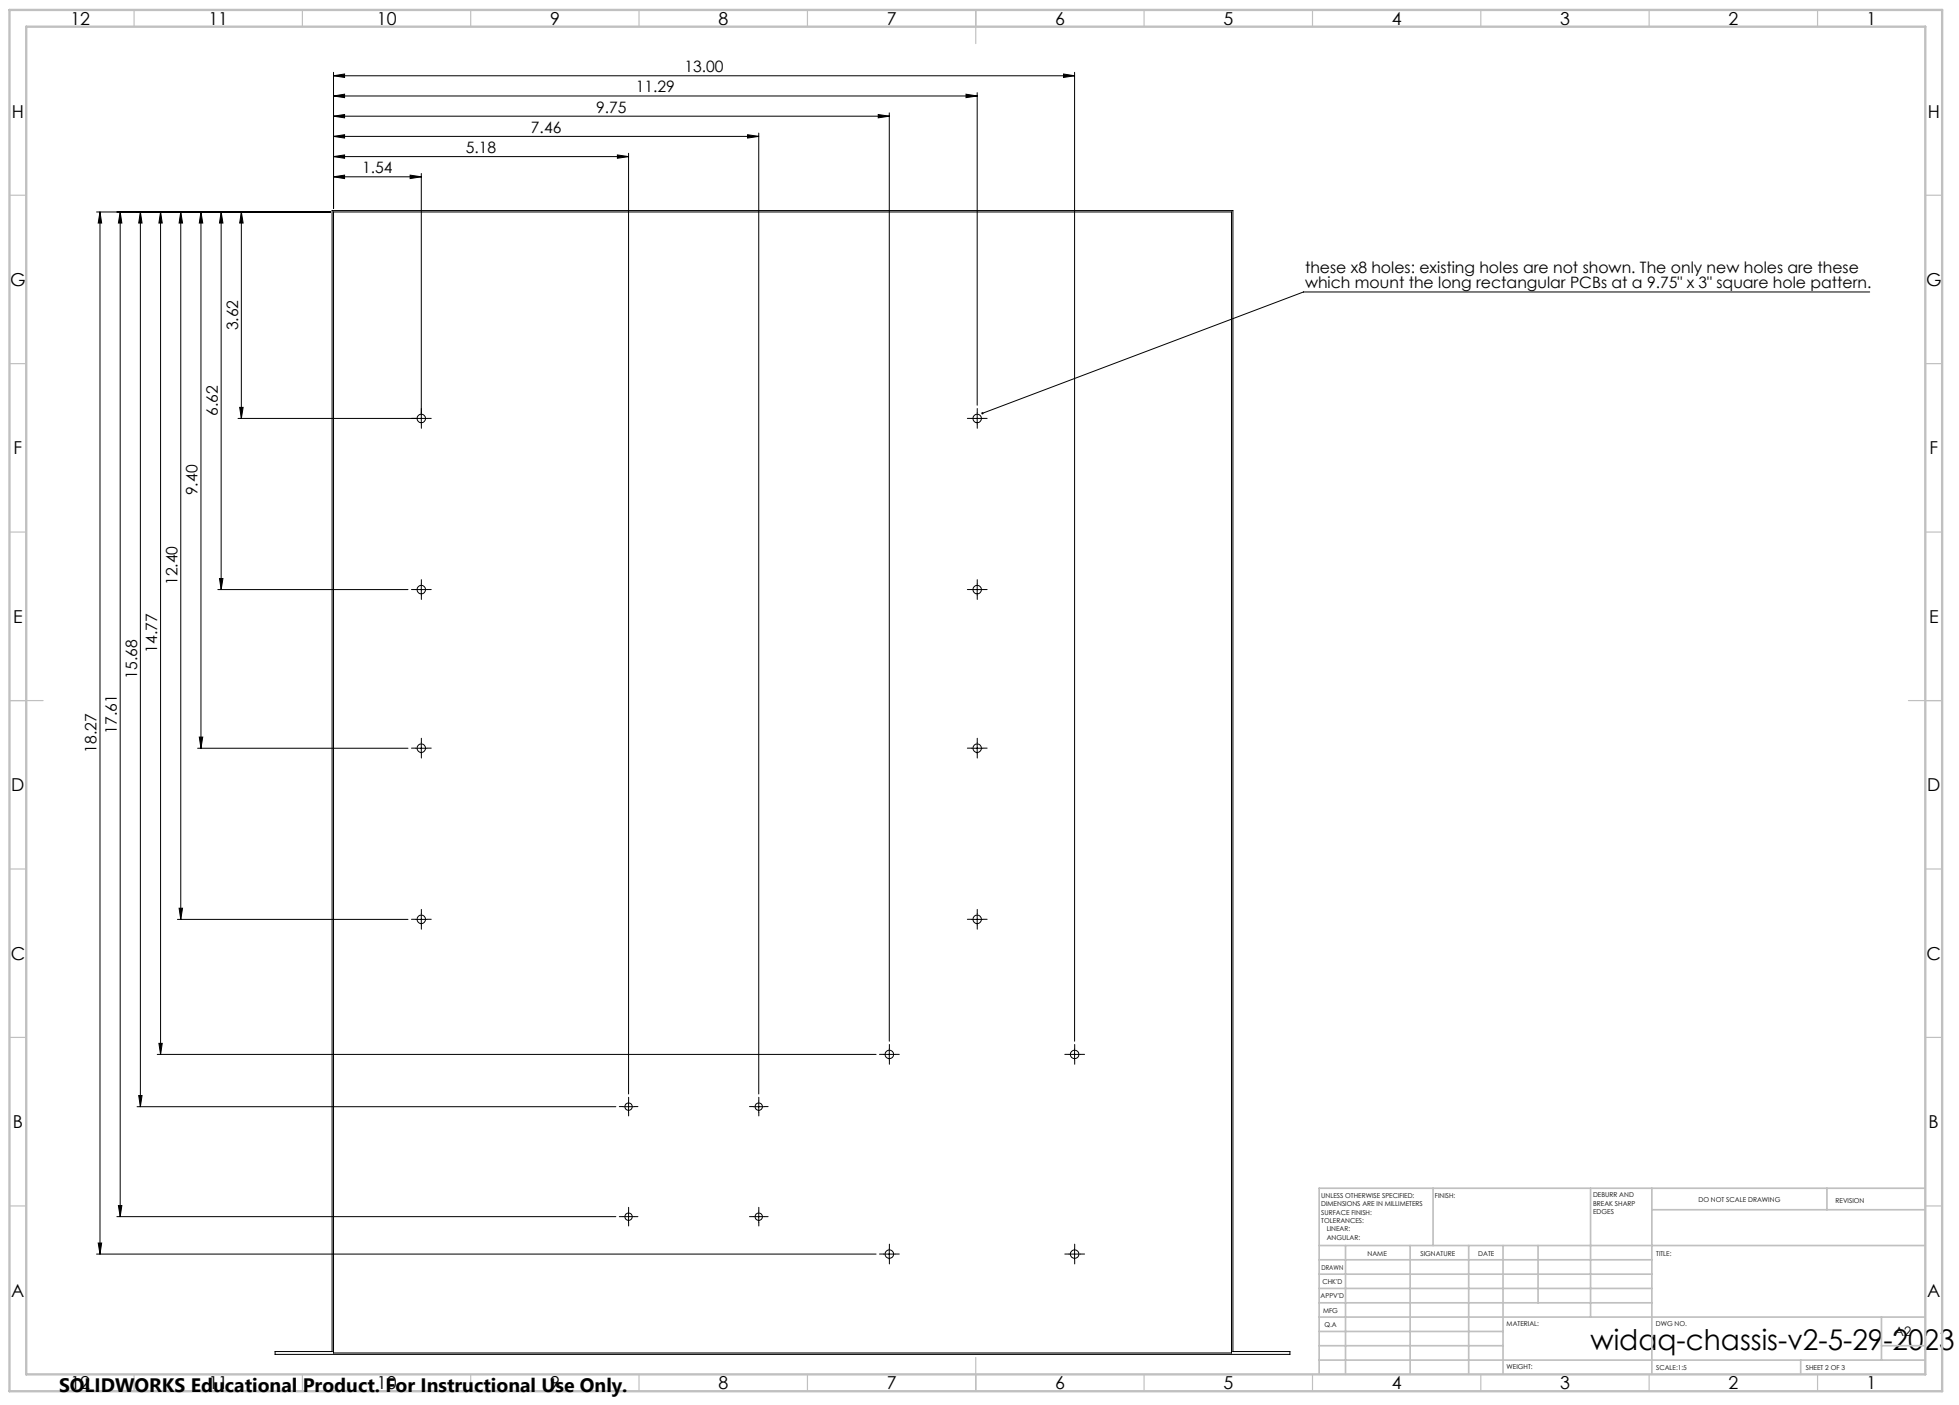
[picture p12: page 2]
FINISH:; DEBURR AND; BREAK SHARP; DO NOT SCALE DRAWING; REVISION

these x8 holes: existing holes are not shown. The only new holes are these
which mount the long rectangular PCBs at a 9.75" x 3" square hole pattern.

UNLESS OTHERWISE SPECIFIED:
DIMENSIONS ARE IN MILLIMETERS
SURFACE FINISH:
TOLERANCES:
LINEAR:
ANGULAR:

NAME | SIGNATURE | DATE | TITLE:

DRAWN
CHK'D

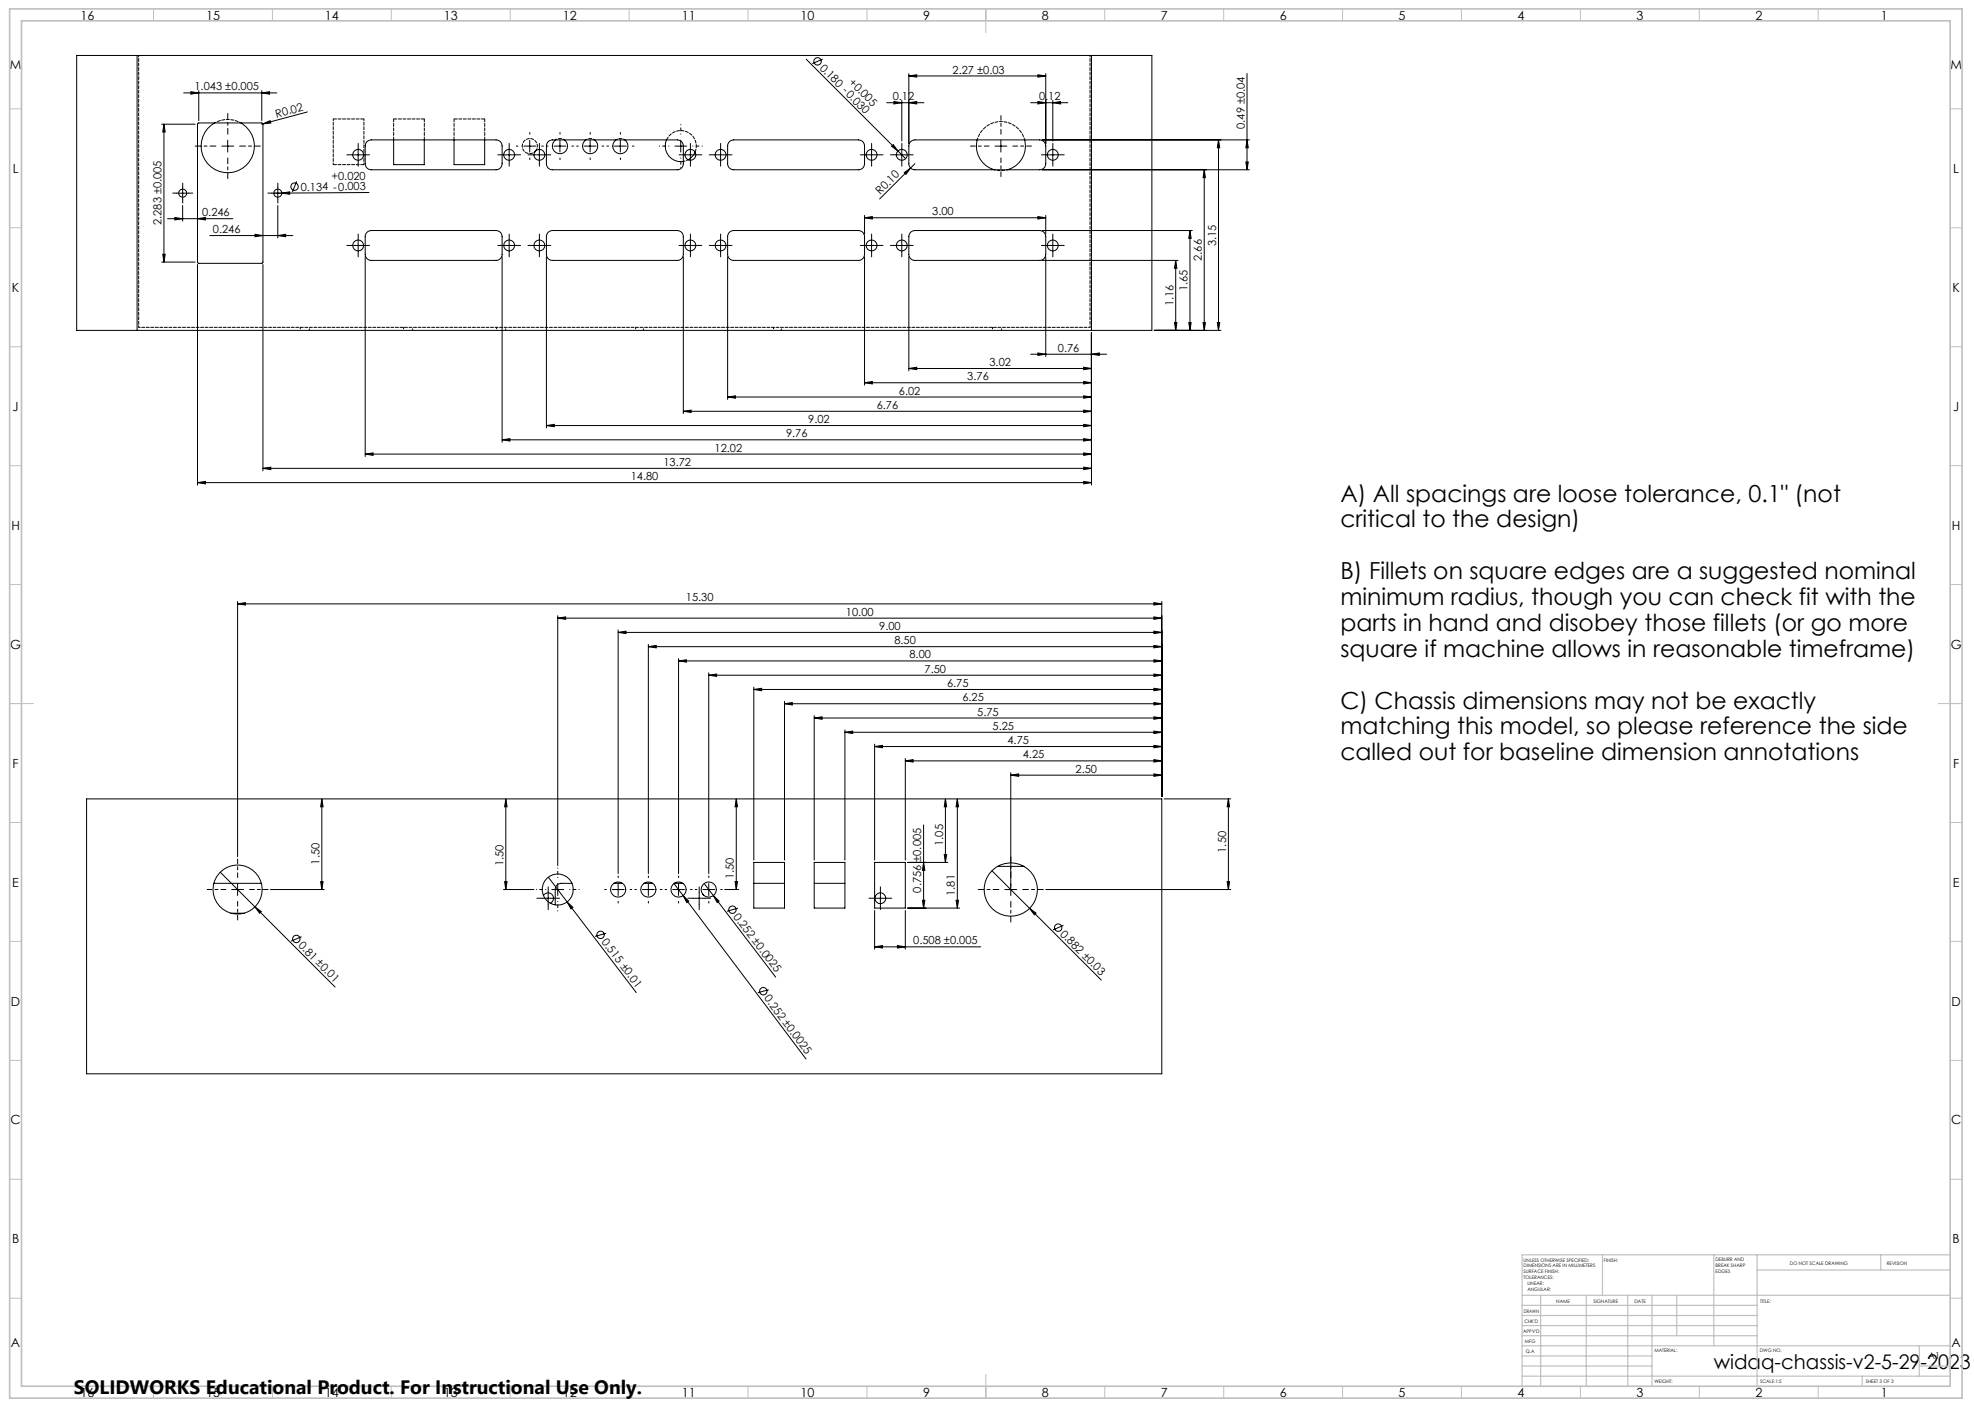
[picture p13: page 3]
FINISH:; DEBURR AND; BREAK SHARP; DO NOT SCALE DRAWING; REVISION

A) All spacings are loose tolerance, 0.1" (not
critical to the design)
B) Fillets on square edges are a suggested nominal
minimum radius, though you can check fit with the
parts in hand and disobey those fillets (or go more
square if machine allows in reasonable timeframe)
C) Chassis dimensions may not be exactly
matching this model, so please reference the side
called out for baseline dimension annotations

UNLESS OTHERWISE SPECIFIED:
DIMENSIONS ARE IN MILLIMETERS
SURFACE FINISH:
TOLERANCES:
LINEAR:
ANGULAR:

NAME | SIGNATURE | DATE | TITLE:

DRAWN
CHK'D

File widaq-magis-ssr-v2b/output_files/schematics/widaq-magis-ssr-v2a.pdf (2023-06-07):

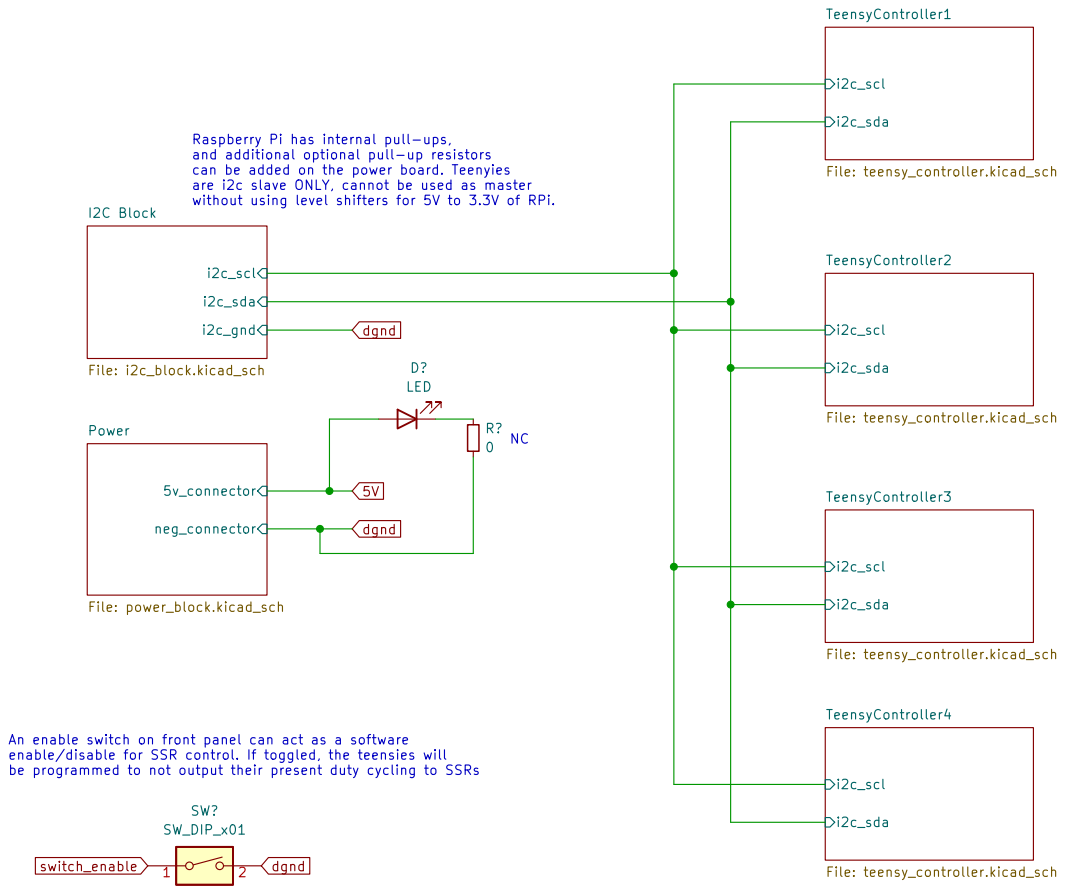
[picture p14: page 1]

Raspberry Pi has internal pull-ups,
and additional optional pull-up resistors
can be added on the power board. Teenyies are i2c slave ONLY, cannot be used as master without using level shifters for 5V to 3.3V of RPi.

An enable switch on front panel can act as a software
enable/disable for SSR control. If toggled, the teensies will

File: widaq-magis-ssr-v2a.kicad_sch Sheet: /
Id: 1/15 Title:

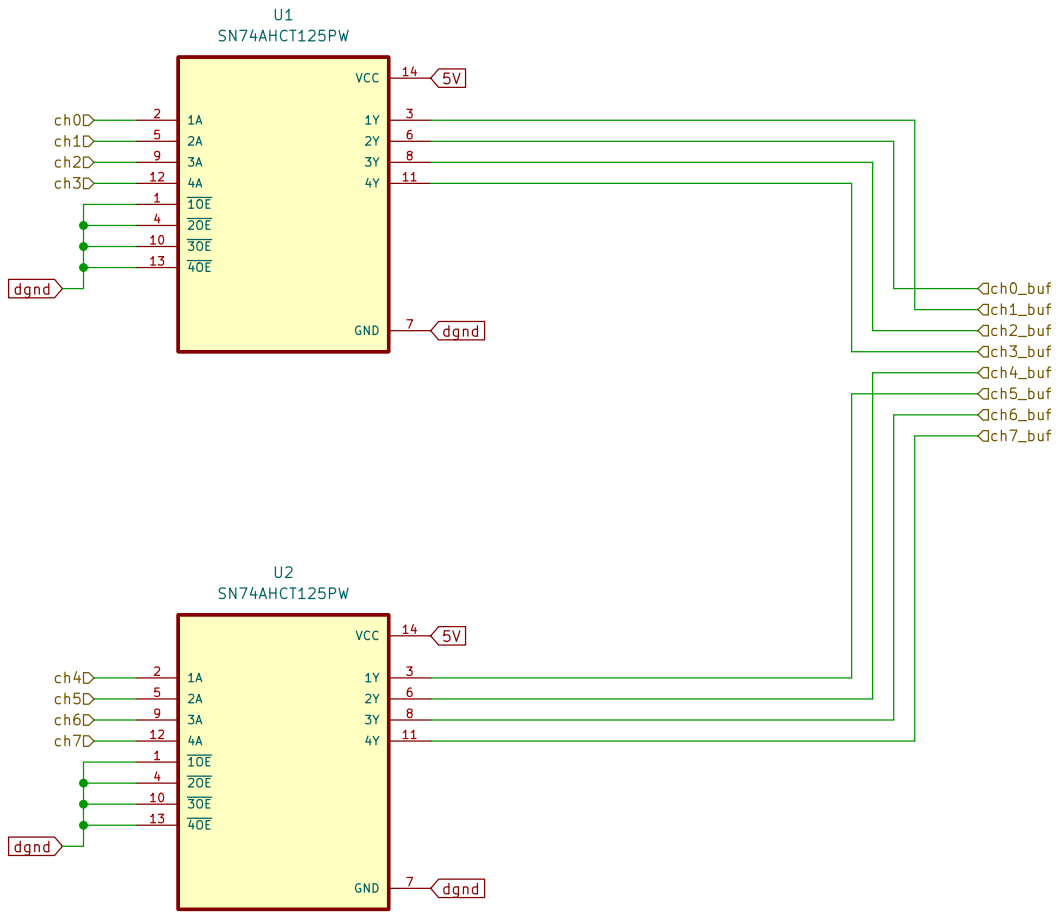
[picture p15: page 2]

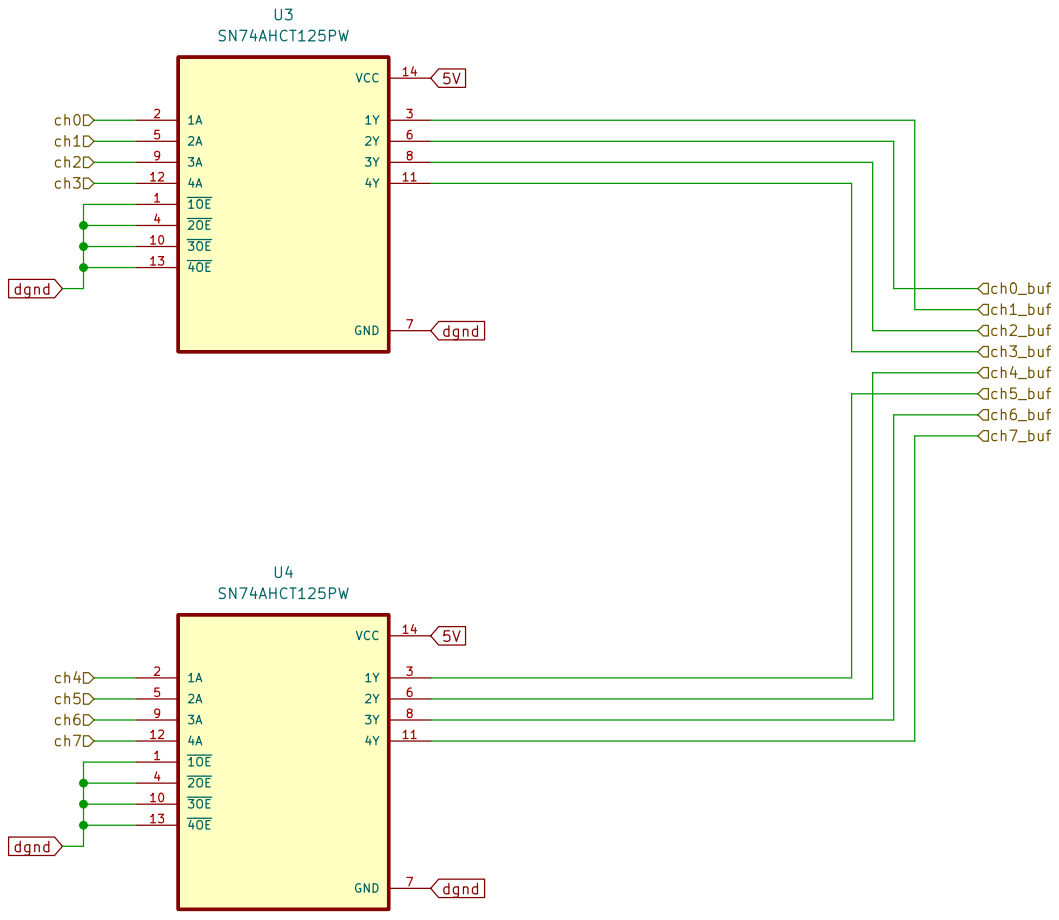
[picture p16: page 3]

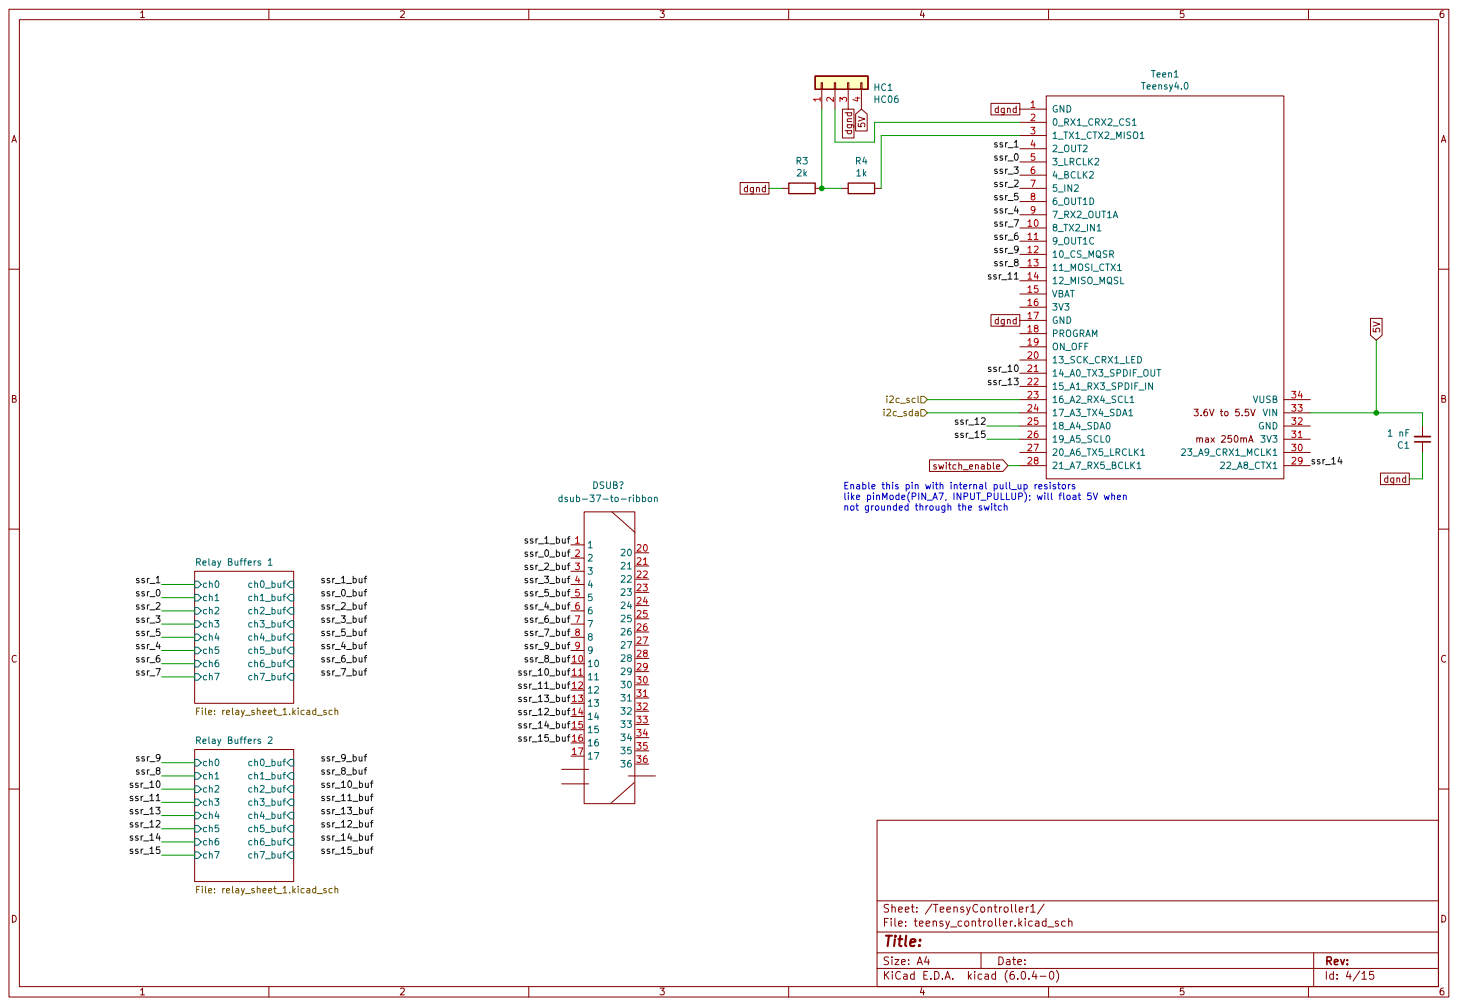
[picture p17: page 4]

like pinMode(PIN_A7, INPUT_PULLUP); will float 5V when
not grounded through the switch

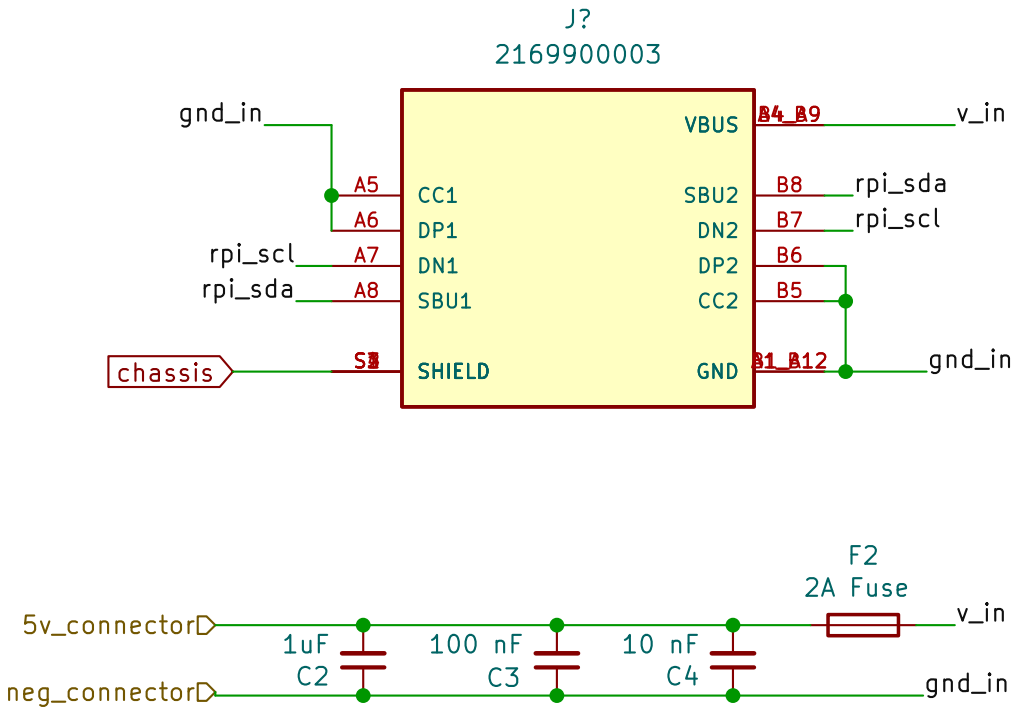
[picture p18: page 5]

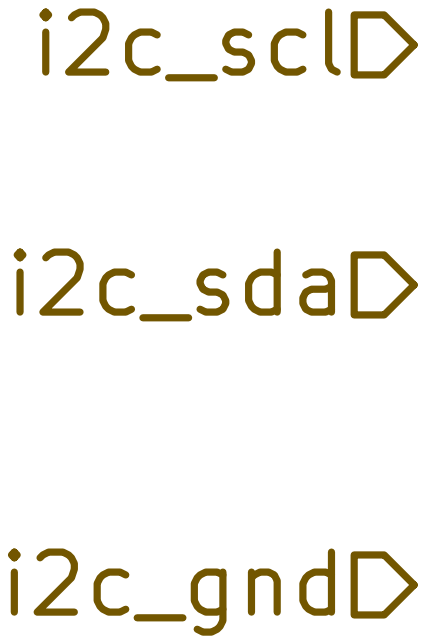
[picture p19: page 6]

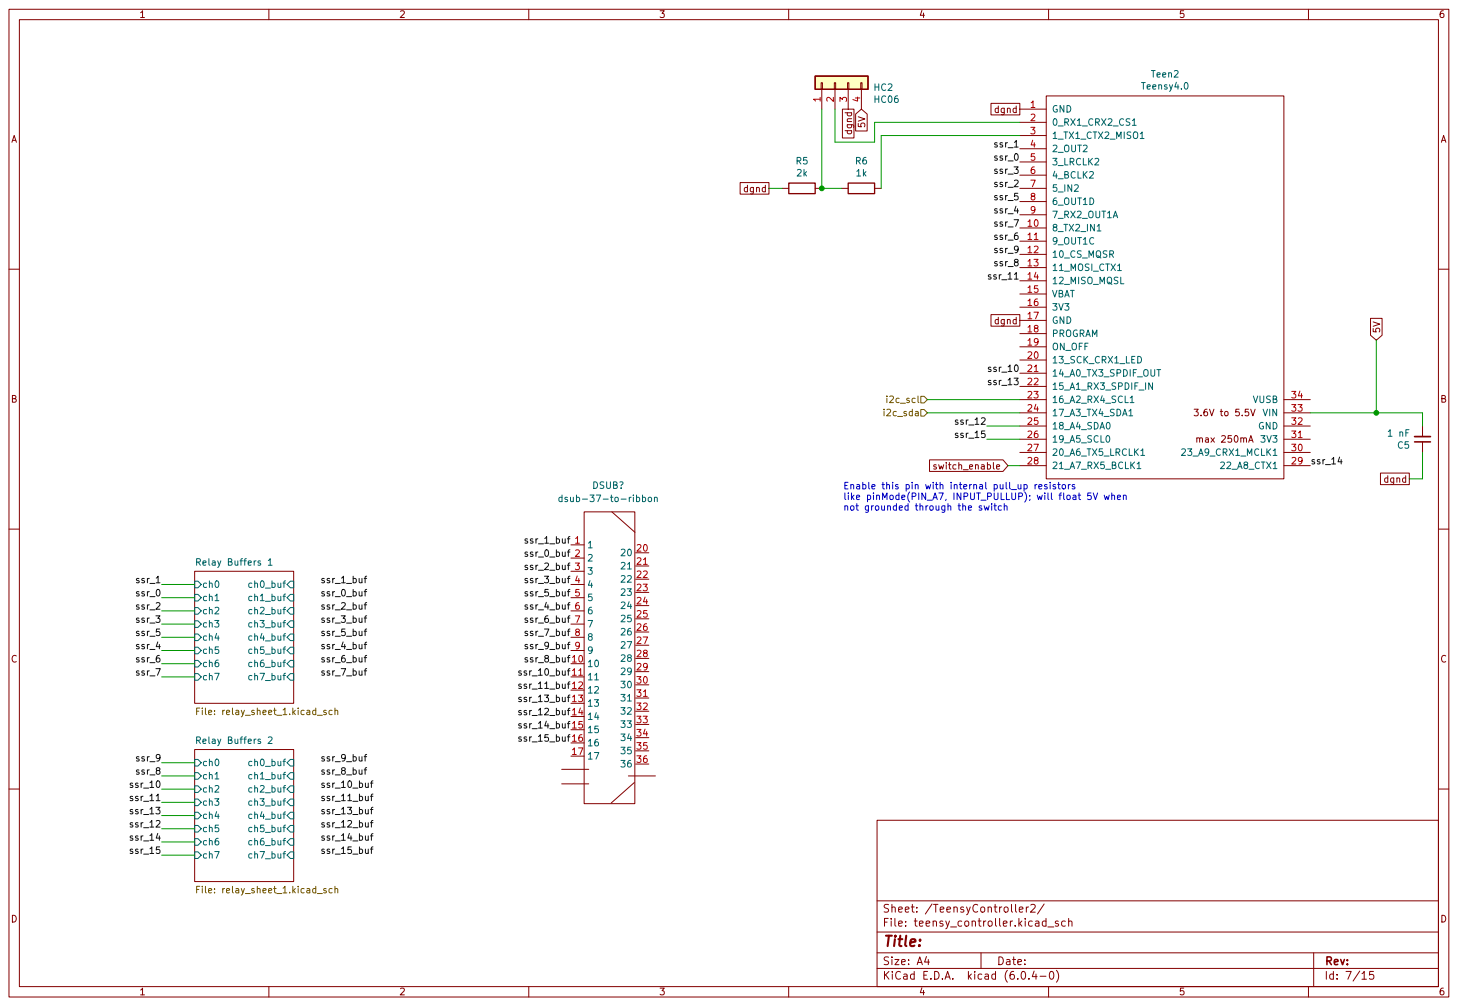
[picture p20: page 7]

like pinMode(PIN_A7, INPUT_PULLUP); will float 5V when
not grounded through the switch

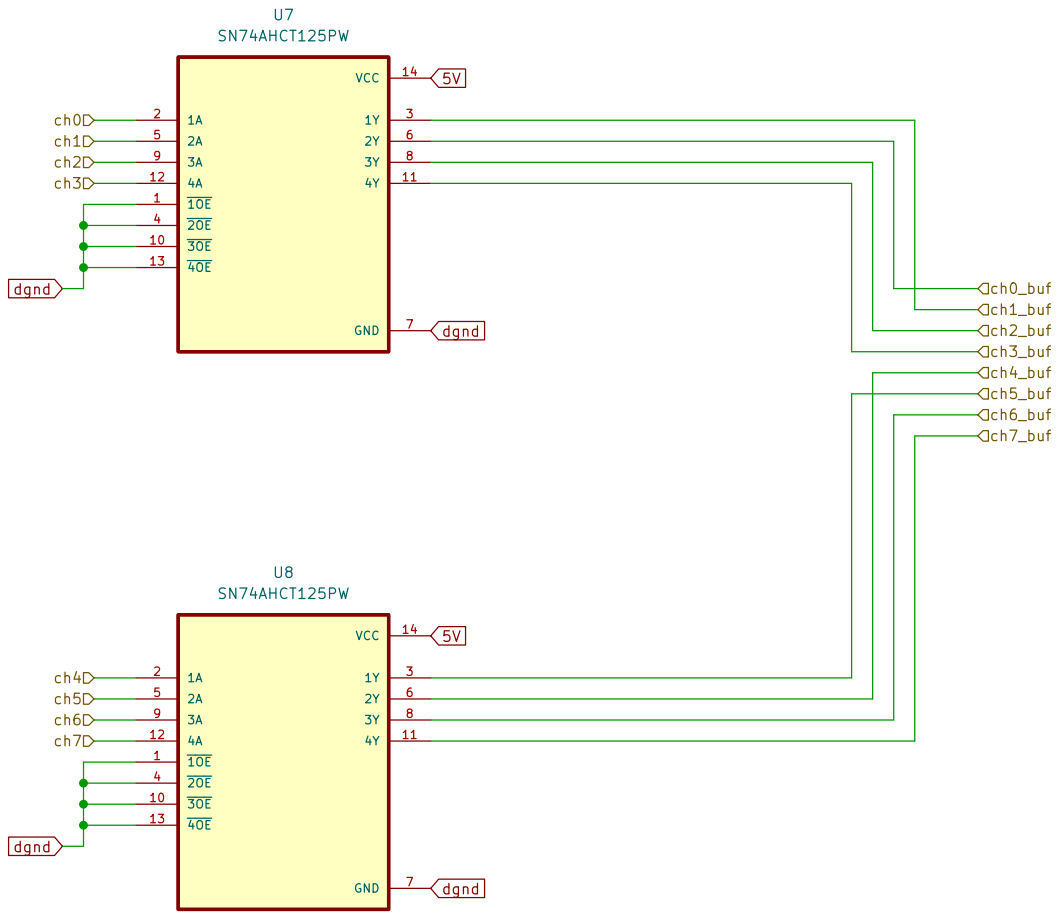
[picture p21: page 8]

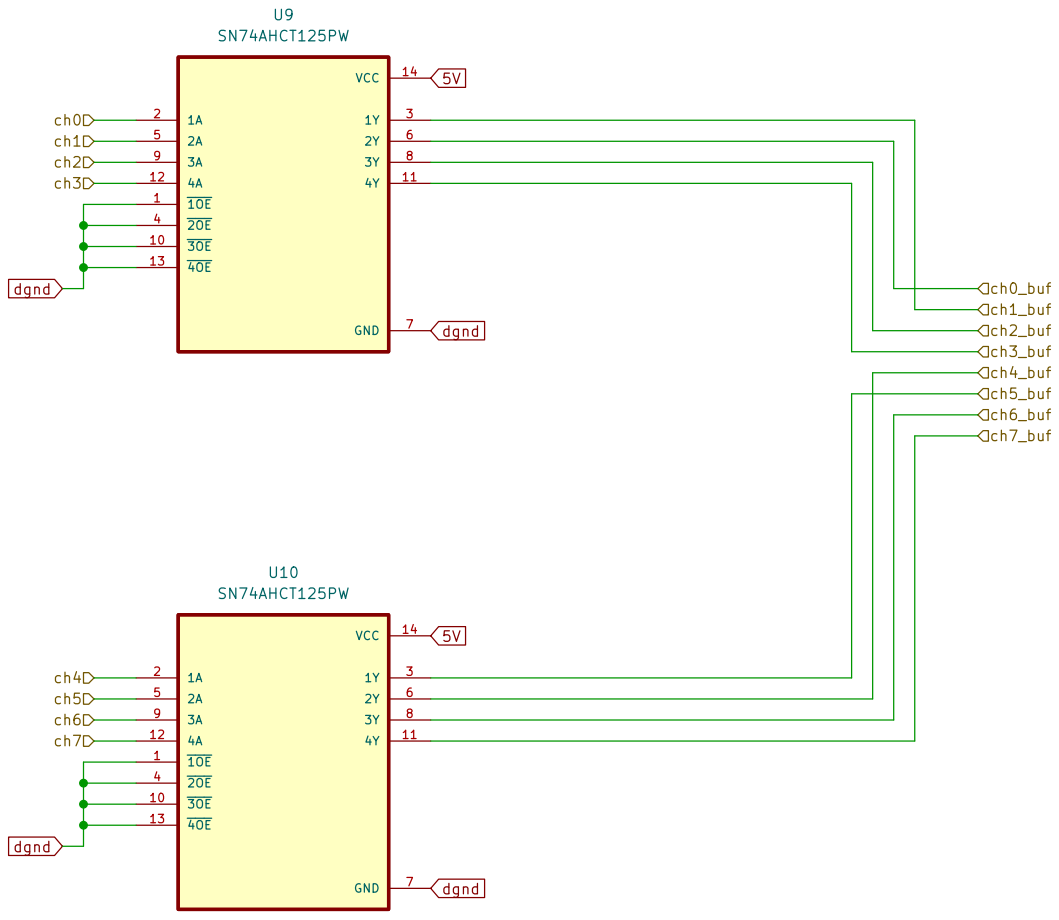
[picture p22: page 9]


like pinMode(PIN_A7, INPUT_PULLUP); will float 5V when
not grounded through the switch




like pinMode(PIN_A7, INPUT_PULLUP); will float 5V when
not grounded through the switch



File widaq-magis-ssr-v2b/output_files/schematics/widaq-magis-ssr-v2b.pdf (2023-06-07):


Raspberry Pi has internal pull-ups,
and additional optional pull-up resistors
can be added on the power board. Teenyies are i2c slave ONLY, cannot be used as master without using level shifters for 5V to 3.3V of RPi.

An enable switch on front panel can act as a software
enable/disable for SSR control. If toggled, the teensies will
be programmed to not output their present duty cycling to SSRs

This button, on the front panel of the chassis,
is routed to each teensy and is intended to send
a digital signal for the Teensy to reset its firmware
to its initial state




This is a backup option for bluetooth communication.
Do not populate upon first assemblyNC

not grounded through the switch NC

Enable this pin with internal pull_up resistors
like pinMode(PIN_A7, INPUT_PULLUP); will float 5V when



This is a backup option for bluetooth communication.
Do not populate upon first assemblyNC

not grounded through the switch NC

Enable this pin with internal pull_up resistors
like pinMode(PIN_A7, INPUT_PULLUP); will float 5V when




This is a backup option for bluetooth communication.
Do not populate upon first assemblyNC

not grounded through the switch NC

Enable this pin with internal pull_up resistors
like pinMode(PIN_A7, INPUT_PULLUP); will float 5V when




This is a backup option for bluetooth communication.
Do not populate upon first assemblyNC

not grounded through the switch NC

Enable this pin with internal pull_up resistors
like pinMode(PIN_A7, INPUT_PULLUP); will float 5V when



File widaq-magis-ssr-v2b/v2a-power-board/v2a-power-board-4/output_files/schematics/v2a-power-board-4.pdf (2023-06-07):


connected to mounting holes

File: v2a-power-board-4.kicad_sch Sheet: /
Id: 1/1 Title:

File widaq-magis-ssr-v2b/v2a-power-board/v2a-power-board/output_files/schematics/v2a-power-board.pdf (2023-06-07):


connected to mounting holes

File: v2a-power-board.kicad_sch Sheet: / C?

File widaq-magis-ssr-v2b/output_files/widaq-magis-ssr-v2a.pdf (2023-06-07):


connected to mounting holes

File: widaq-magis-ssr-v2a.sch Sheet: /
Id: 1/3 Title:






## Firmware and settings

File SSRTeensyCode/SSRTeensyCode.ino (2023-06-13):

/********************************************************************************************************
* This code allow a teensy micro controller to be remote controlled through an HC-06 bluetooth module and
* set the duty cycle of Solid State Relay (SSR) via pulse width modulation.
* The SSR can have its duty cycle set directly or set via a PID loop using 
* tempurature as error parremeter.
* File name: MAGIS_SSR_PWM_16_Channel_Jan03_2023
**********************************************************************************************************/
#include <vector>
#include <tuple>
#include <string>
#include <sstream>
#include <iomanip>
#include <math.h>
#include <stdio.h>
//#include <SoftwareSerial.h>
#define hc Serial1

#define USING_MICROS_RESOLUTION       true  //false
#include "Teensy_Slow_PWM.h"
// #include <SimpleTimer.h>   // https://urldefense.proofpoint.com/v2/url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 

// Used to indicate errors in function returns.
#define ERROR_TEMP -6666.0
#define EARLIEST_TIME 1577836800

/////////////////////////////////////
//Start lines for Slow PWM objects
#if defined(__IMXRT1062__)
  // For Teensy 4.0 and 4.1
  // Don't change these numbers to make higher Timer freq. System can hang
  #define HW_TIMER_INTERVAL_MS        0.01f
  #define HW_TIMER_INTERVAL_FREQ      100000L
#else
  // Don't change these numbers to make higher Timer freq. System can hang
  #define HW_TIMER_INTERVAL_MS        0.1f
  #define HW_TIMER_INTERVAL_FREQ      10000L
#endif
#define USING_HW_TIMER_INTERVAL_MS        true
volatile uint32_t startMicros = 0;

//these two lines are to fix an error in the linker
//of C, which is pretty dependent on (1) which teensyduino
//ide you are user, whether in "Tools > Optimize" you are set
//to "Faster", or other factors. It is related to copy constructor
//of vectors and strings in STL. 
unsigned __exidx_start;
unsigned __exidx_end;

// Create a buffer for the bluetooth serial receive
int const bufCount = 1024;
unsigned char ser1buf[1024];

//Timer object, selects TEENSY_TIMER_1 from hardware definitions.
//Don't change that number unless you read the manual of TeensyTimer
TeensyTimer ITimer(TEENSY_TIMER_1);

// Init Teensy_SLOW_PWM, each can service 16 different ISR-based PWM channels
Teensy_SLOW_PWM ISR_PWM;
float PWM_Freq = 5.0f; //Hz

void TimerHandler()
{ 
  ISR_PWM.run();
}
//End Slow PWM object setup
////////////////////////////////////



// Indicates which pins of the Teensy are connected to the serial pins of the HC-06
//const int blueRx = 0;
//const int blueTx = 1;
//SoftwareSerial hc(blueRx, blueTx);

// Indicates which pins of the Teensy are connected to the SSR control pins/lines.
const int numberOfRelays = 16;

//for the PCB version "ssr-v1b" which is a single Teensy, 16 SSR controller prototype board with terminal block connector
const int relayPinList[numberOfRelays] = {3, 2, 5, 4, 7, 6, 9, 8, 11, 10, 14, 12, 18, 15, 22, 19};

//for the PCB version "ssr-v2b" that is meant for 4 Teensy's
//const int relayPinList[numberOfRelays] = {2, 3, 4, 5, 6, 7, 8, 9, 10, 11, 12, 14, 15, 18, 19, 22};

const String teensyID = "Magis_SSR_Teensy";
String bluetoothBuffer = "";

char print_buf[250]; // For printing errors easily


// This is class which creates a PID controller for one SSR output
// for details on how a PID loop works read this wiki article: https://urldefense.proofpoint.com/v2/url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 
class SSRController {
  public:
  
    SSRController(){}
    SSRController(int SSRPin)
    {
      _pin = SSRPin;
      setupPWM();
      setDutyCycle(0.0);
    }
    ~SSRController(){}

    // State indicates the type of set point function the PID controller should use.
    // CONST indicates a constant tempurature that the controller aims for
    // RAMP indicates a linear increase or decrease in tempureture
    // POWER_OFF sets the duty cycle to 0
    enum State { CONST, RAMP, POWER_OFF, MANUAL };
    State current_state = State::POWER_OFF;
    
    float getDutyCycle()
    {
      return duty_cycle;
    }
    
    void enterNewPIDParameters(float newKP, float newKI, float newKD)
    {
      K_p = newKP;
      K_i = newKI;
      K_d = newKD;
    }
    
    void enterNewSetPoint(State newState, float newTarget, float newRamp, long long newStartTime, float newStartTemp)
    {
      if (newState == State::POWER_OFF)
      {
        setDutyCycle(0.0);
      }

      if (newState == State::MANUAL)
      {
        target_temp = newTarget;
        setDutyCycle(newTarget);
      }
      
      current_state = newState;
      target_temp = newTarget;
      ramp = newRamp;
      start_time = newStartTime;
      start_temp = newStartTemp;
    }
    
    void enterNewTemp(float temp, long long time_ms)
    {
      if(temp_record.size() > MAX_RECORD_SIZE)
      {
        temp_record.erase(temp_record.begin());
        error_record.erase(error_record.begin());
      }
        
      temp_record.push_back(std::tuple<float, long long>(temp, time_ms));
      //        Serial.print("New temp added ");
      //        Serial.println(temp);
      if(current_state != State::POWER_OFF){
        float set_point_temp = set_point_func(time_ms);
        float error = set_point_temp - temp;
        error_record.push_back(std::tuple<float, long long>(error, time_ms));
      //          sprintf(print_buf, "New Record\terror: %f\ttemp: %f\tset point: %f", error, temp, set_point_temp);
      //          Serial.println(print_buf);
      } else {
        error_record.push_back(std::tuple<float, long long>(0.0, time_ms));
      }
    }

    
    void updatePID()
    {
      if(current_state == State::POWER_OFF)
      {
        setDutyCycle(0.0);
        return;
      }

      if(current_state == State::MANUAL)
      {
        setDutyCycle(target_temp);
        return;
      }
    
      int record_length = error_record.size();
    
      if(record_length < 2)
      {
        return;
      } 
    
      float proportional = std::get<0>(error_record[record_length-1]);
    
      float integral = 0;
      for(int i = 1; i < record_length; i++)
      {
        std::tuple<float, long long> prev_error = error_record[i-1];
        std::tuple<float, long long> curr_error = error_record[i];
        float average_temp = (std::get<0>(curr_error) + std::get<0>(prev_error))/2.0;
        long long delta_t = std::get<1>(curr_error) - std::get<1>(prev_error);
        //        sprintf(print_buf, "Average error: %f, delta t: %lld", average_temp, delta_t);
        //        Serial.println(print_buf);
        if(delta_t > 60*1000 || delta_t < 0)
        {
          Serial.print("ERROR: Invalid time difference: ");
          //Serial.println(delta_t);
          //Serial.println(std::get<1>(curr_error));
          //Serial.println(std::get<1>(prev_error));
          error_record.erase(error_record.begin() + i - 1);
          temp_record.erase(temp_record.begin() + i - 1);
          error_record.erase(error_record.begin() + i);
          temp_record.erase(temp_record.begin() + i);
          i--;
          delta_t = 0;
        }
        integral += average_temp*delta_t;
      }
    
      //      sprintf(print_buf, "Total integral: %f Total time: %lld", integral, std::get<1>(error_record[record_length-1]) - std::get<1>(error_record[0]));
      //      Serial.println(print_buf);
      integral = integral/(std::get<1>(error_record[record_length-1]) - std::get<1>(error_record[0]));
    
      std::tuple<float, long long> prev_error = error_record[record_length - 2];
      std::tuple<float, long long> curr_error = error_record[record_length - 1];
    
      int time_delta = std::get<1>(curr_error) - std::get<1>(prev_error);
      float derivative = 0;
      if(time_delta > 0)
      {
        derivative = (std::get<0>(curr_error) - std::get<0>(prev_error))/time_delta;  
      }
      
    
      float u = K_p*proportional + K_i*integral + K_d*derivative;
      if(u > 100.0)
      {
        u = 100.0;
      }
      
      else if (u < 0.0)
      {
        u = 0.0;
      }
      
    
      sprintf(print_buf, "PID out put was : %f\n\nType\tError\tScaled\nP:\t%f\t%f\nI:\t%f\t%f\nD:\t%f\t%f", u, proportional, K_p*proportional, integral, K_i*integral, derivative, K_d*derivative);
      Serial.println(print_buf);
      setDutyCycle(u);
    }

    
  private:
    // Constants
    const unsigned int MAX_RECORD_SIZE = 60*2; // 2 minutes of record time
  
    // Basic control
    // The pin of the SSR
    int _pin;
    int _isrChan; //the isr channel number referenced by Slow_PWM object
    
    float duty_cycle = 0.0; //from 0 to 100

    
    // Vectors containing prior tempuratures and how far they were from the set function
    std::vector<std::tuple<float, long long>> error_record;
    std::vector<std::tuple<float, long long>> temp_record;

    long long start_time; // In millisecond from Jan 1, 1979 GMT
    float ramp; // In Celcius per millisecond
    float target_temp; // In Celcius
    float start_temp; // In Celcius

    // Parameters for the PID loop
    float THERMAL_MASS = 1.0; // Celcius / Jule 
    float K_p = 30.0; // 11 * Watts per Centigrad = 11 * J/(C*s)
    float K_i = 1.0;  // 11 * Watts per Centigrad Milliseconds = 0.011 * J/(C*s^2)
    float K_d = 1000*2*sqrt(THERMAL_MASS*K_p);    // 11 * Watts Milliseconds per Cenrigrad = 11,000 * J/C

    

    void setupPWM()
    {
      _isrChan = ISR_PWM.setPWM(_pin, PWM_Freq, 0); //initial duty cycle is 0, don't power yet
    }
    
    void setDutyCycle(float percentage)
    {
      duty_cycle = percentage;
      Serial.print(_isrChan);
      Serial.print(": Set duty cycle to new value: ");
      Serial.println(getDutyCycle());
      //the line in the if statement modifies the duty cycle.  
      if(!ISR_PWM.modifyPWMChannel(_isrChan, _pin, PWM_Freq, duty_cycle))
      {
        Serial.print(F("modifyPWMChannel error on channel: "));
        Serial.println(_pin);
      }
    }
    
    float set_point_func(long long time_ms)
    {
      switch(current_state) 
      {
        case State::CONST:
        return target_temp;
        case State::RAMP:
        {
          if(start_time > time_ms) 
          {
            return start_temp;
          }
          int delta_t = (int)(time_ms - start_time);
          float possible_temp = ramp*delta_t + start_temp;
          if((possible_temp > target_temp && ramp > 0) || (possible_temp < target_temp && ramp < 0))
          {
            return target_temp;
          }
          else
          {
            return possible_temp;
          }
        }
        case State::POWER_OFF:
        case State::MANUAL:
        default:
        return ERROR_TEMP;
      }
    }  
};



// An array of SSR controller pointers to allow 
//the teensy to control multiple channels.
SSRController *Controllers[numberOfRelays]; //initialized in setup

std::string firstHalfOfSplitMessage(""); // HC06 will send data at random time intervals so sometimes messages will be 
// cutoff at the end of one buffer and continue at the start of the next.  This string stores the cut off message so it can be recombined.



int count_substring(std::string s, std::string target){
  int occurrences = 0;
  std::string::size_type pos = 0;
  while ((pos = s.find(target, pos )) != std::string::npos) {
    occurrences++;
    pos++;
  }
  return occurrences;
}


// Message Type indicates the type of message sent from the bluetooth module
// NONE indicates some sort of error
// TEMP_SET indicates a comand to set the PID controller set point function for one SSR
// TEMP_CUR indicates the tempurature recorded and the time it was recorded.
enum MessageType { NONE, TEMP_SET, TEMP_CUR };

MessageType parseChannelMessage(std::string msg, SSRController *thisController);

MessageType parseChannelMessage(std::string msg, SSRController *thisController) {
  if(count_substring(msg, std::string("TEMP_SET=")) + count_substring(msg, std::string("TEMP_CUR=")) > 1){
      sprintf(print_buf, "ERROR: received frankenstien message: %s<NEWLINETEST>", msg.c_str());
      Serial.println(print_buf);
      return MessageType::NONE;
    }
  
    if (msg.substr(0,9) == "TEMP_SET=") {
      size_t commas[4];
      size_t last_comma = 9;
      for(int i = 0; i < 4; i++) {
        commas[i] = msg.find_first_of(",", last_comma+1);
        if(commas[i] == std::string::npos){
          sprintf(print_buf, "ERROR: TEMP_SET message failed to parse due to absense of a comma. \n See message: %s", msg.c_str());
          Serial.println(print_buf);
          return MessageType::NONE;
        }
        last_comma = commas[i];
      }
      
      std::string state = msg.substr(9, commas[0] - 9);
      SSRController::State newState = SSRController::State::POWER_OFF;
      float target_temp = ERROR_TEMP;
      float ramp = ERROR_TEMP;
      long long start_time = 0;
      float start_temp = -1 * ERROR_TEMP; // This needs to be positive and large so that at no point does the PID think
      // that the current temperature is very far below the setpoint, which would turn the heater on full blast momentarily
      // which is not desired
      
      Serial.println(state.c_str());
      if (state.compare("POWER_OFF") == 0) {
        newState = SSRController::State::POWER_OFF;
        Serial.println("POWER_OFF: Shutting down SSR.");
      } else if (state.compare("MANUAL") == 0) {
        newState = SSRController::State::MANUAL;
        target_temp = atof(msg.substr(commas[0]+1, commas[1]-commas[0]).c_str());
        sprintf(print_buf, "Manually setting duty cycle to %f", target_temp);
        Serial.println(print_buf);
      } else if (state.compare("CONST") == 0) {
        newState = SSRController::State::CONST;
        target_temp = atof(msg.substr(commas[0]+1, commas[1]-commas[0]).c_str());
        sprintf(print_buf, "Setting constant tempurature to %f", target_temp);
        Serial.println(print_buf);
      } else if (state.compare("RAMP") == 0) {
        newState = SSRController::State::RAMP;
        target_temp = atof(msg.substr(commas[0]+1, commas[1]-commas[0]).c_str());
        ramp = atof(msg.substr(commas[1]+1, commas[2] - commas[1]).c_str());
        start_time = strtoll(msg.substr(commas[2]+1, commas[3] - commas[2]).c_str(), NULL, 0);
        start_temp = atof(msg.substr(commas[3]+1).c_str());
        sprintf(print_buf, "Starting ramp: %f, %f, %lld, %f", target_temp, ramp, start_time, start_temp);
        Serial.println(print_buf);
      } else {
        sprintf(print_buf, "ERROR: TEMP_SET had invalid state. \n See message: %s", msg.c_str());
        Serial.println(print_buf);
        return MessageType::NONE; 
      }

      thisController->enterNewSetPoint(newState, target_temp, ramp, start_time, start_temp);
      return MessageType::TEMP_SET;
    } 

    //set parameters of the PID loop, p, i, and d
    if(msg.substr(0,9) == "PIDP_SET=") {
      size_t commas[2];
      size_t last_comma = 9;
      for(int i = 0; i < 2; i++) {
        commas[i] = msg.find_first_of(",", last_comma+1);
        if(commas[i] == std::string::npos){
          sprintf(print_buf, "ERROR: TEMP_SET message failed to parse due to absense of a comma. \n See message: %s", msg.c_str());
          Serial.println(print_buf);
          return MessageType::NONE;
        }
        last_comma = commas[i];
      }
      float K_p = atof(msg.substr(9, commas[0]).c_str());
      float K_i = atof(msg.substr(commas[0]+1, commas[1] - commas[0]).c_str());
      float K_d = atof(msg.substr(commas[1]+1).c_str());
      sprintf(print_buf, "Setting PID parameters to: %f, %f, %f", K_p, K_i, K_d);
      Serial.println(print_buf);

      thisController->enterNewPIDParameters(K_p, K_i, K_d);
    }
    
    if (msg.substr(0,9) == "TEMP_CUR=") {
      size_t comma_loc = msg.find(",", 9);
      if(comma_loc == std::string::npos){
        sprintf(print_buf, "ERROR: TEMP_CUR message failed to parse due to absense of a comma. \n See message: %s", msg.c_str());
        Serial.println(print_buf);
        return MessageType::NONE;
      }
      float temp = atof(msg.substr(9, comma_loc - 9).c_str());
      long long time_ms = strtoll(msg.substr(comma_loc+1).c_str(), NULL, 0);
      if (time_ms < EARLIEST_TIME) {
        sprintf(print_buf, "Recieved invalid time: %lld from message %s<NEWLINETEST>", time_ms, msg.c_str());
        Serial.println(print_buf);
        return MessageType:: NONE;
      }
//      sprintf(print_buf, "Recieved current tempurature: %f at time %lld\n", temp, time_ms);
//      Serial.println(print_buf);
      thisController->enterNewTemp(temp, time_ms);
      thisController->updatePID();
      return MessageType::TEMP_CUR; 
    }

    return MessageType::NONE;
}

MessageType parseBluetoothMessage(std::string msg);

MessageType parseBluetoothMessage(std::string msg){
    if (msg[0] != '#'){
      sprintf(print_buf, "ERROR: received message without opening hashtag: %s", msg.c_str());
      Serial.println(print_buf);
      return MessageType::NONE;
    }

    uint colon_pos = msg.find_first_of(":");

    if(colon_pos == std::string::npos) {
      sprintf(print_buf, "ERROR: received message without seperating colon: %s", msg.c_str());
      Serial.println(print_buf);
      return MessageType::NONE;
    }
    std::string channel_str = msg.substr(1,colon_pos);

    int channel_index = atoi(channel_str.c_str());
    
    if(channel_index >= numberOfRelays){
      sprintf(print_buf, "ERROR: received message with channel out of range 0 to %d: %s", numberOfRelays-1, channel_str.c_str());
      Serial.println(print_buf);
      return MessageType::NONE;
    }
    
    if(channel_index == -1){
      sprintf(print_buf, "ERROR: received message without valid channel: %s", channel_str.c_str());
      Serial.println(print_buf);
      return MessageType::NONE;
    }
    
    SSRController *thisController = Controllers[channel_index];
    return parseChannelMessage(msg.substr(colon_pos+1), thisController);
}


void parseBluetoothBuffer(String bluetoothBuffer){
  std::string buf(bluetoothBuffer.c_str());
  std::vector<std::string> lines; 

  // Loop through the bluetooth buffer and seperate lines into individual messages
  size_t old_found = -1;
  size_t found = 0;
  std::string message = "";
  while(found != std::string::npos){
    found = buf.find_first_of("\n", old_found+1);

    message = "";
    if(found != std::string::npos){
      message = buf.substr(old_found+1, found-old_found-1);
    } 
    else if(found+1 < buf.length()) { // This condition means that the buffer did not end in a newline.
      // Therefore, the message is cutoff and we need to store the cutoff half.
      firstHalfOfSplitMessage = buf.substr(old_found+1, buf.length()-old_found-1);
    }
    
    if(old_found == (const size_t)-1 && firstHalfOfSplitMessage.length() != 0){ // recombine split messages.
      message = firstHalfOfSplitMessage + message;
      firstHalfOfSplitMessage = "";
    }

    if(message.length() > 1) {
       parseBluetoothMessage(message); 
    }
      
    old_found = found;
  }
}


// Initialize all of pins need, the serial channel for connecting to the HC-06 bluetooth module,
// and initialize a normal serial output for debuging
void setup()   {  
  //setup bluetooth communication
  hc.addMemoryForRead(ser1buf,bufCount);
  hc.begin(9600);
  while(hc.available())
  {
    hc.read();
  }

  Serial.begin(9600);
  Serial.println("Testing Magis SSR");
  Serial.println(teensyID);

  ////////////////////////////////
  //Setup associated with Slow PWM
  #if USING_HW_TIMER_INTERVAL_MS
    // Interval in microsecs
    if (ITimer.attachInterruptInterval(HW_TIMER_INTERVAL_MS * 1000, TimerHandler))
    {
      startMicros = micros();
      Serial.print(F("Starting ITimer OK, micros() = ")); Serial.println(startMicros);
    }
    else
      Serial.println(F("Can't set ITimer correctly. Select another freq. or interval"));
      
  #else
  
    if (ITimer.attachInterrupt(HW_TIMER_INTERVAL_FREQ, TimerHandler))
    {
      Serial.print(F("Starting  ITimer OK, micros() = ")); Serial.println(micros());
    }
    else
      Serial.println(F("Can't set ITimer. Select another freq. or timer"));
      
  #endif
  //End Slow PWM setup
  ////////////////////////////////

  //this SSRController construction initializes the ISR_PWM channels, calling setPWM. 
  //(thus must come after the ISR_PWM setup above). 
  for(int i = 0; i < numberOfRelays; i++) {
    Controllers[i] = new SSRController(relayPinList[i]);              
  }

  
}

bool heartbeat = true;

extern float tempmonGetTemp(void);
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
void loop() {
  numberOfSecondsWithoutMessage++;

  //commenting this out while debugging
  
  while(hc.available()) {
    bluetoothBuffer = hc.readString();
    Serial.println(bluetoothBuffer);  
    parseBluetoothBuffer(bluetoothBuffer);
    numberOfSecondsWithoutMessage = 0;
  }


  /*
  //serial as the message interface, for debugging
  //comment this out when not using, comment out
  //bluetooth mode when using. 
  while(Serial.available()) {
    bluetoothBuffer = Serial.readString();
    Serial.println(bluetoothBuffer);  
    parseBluetoothBuffer(bluetoothBuffer);
    numberOfSecondsWithoutMessage = 0;
  }
  */

  
  if(numberOfSecondsWithoutMessage > 60) {
    Serial.println("ERROR: No bluetooth messages for over a minute. Shuting down Solid State Relays to avoid uncontrolled heating.");
    for (int i = 0; i < numberOfRelays; i++) {
      Controllers[i]->enterNewSetPoint(SSRController::State::POWER_OFF, 0.0, 0.0, 0.0, 0.0); 
    }
    numberOfSecondsWithoutMessage = 0;
  }
  
  sendHeartBeatPacket();
  delay(1000);
}

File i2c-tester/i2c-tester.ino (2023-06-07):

// Wire Slave Sender
// by Nicholas Zambetti <http://www.zambetti.com>
// Modified by Richard Gemmell Oct 2019

// Demonstrates use of the Wire library
// Sends data as an I2C/TWI slave device
// Refer to the "Wire Master Reader" example for use with this
// To use it, connect a master to the Teensy on pins 16 and 17.
//
// Consider using the I2CRegisterSlave class instead of Wire to
// create an I2C slave.

// Created 29 March 2006

// This example code is in the public domain.

#include <Arduino.h>
#include <i2c_driver.h>
#include <i2c_driver_wire.h>
#include <string.h>

void requestEvent(); //when RPi requests data from arduino, call this function to send duty cycles to RPi
void receiveEvent(int _); //when RPi sends data to this device, call this function to parse. the int arg is required by Wire library

const int N = 16; //number of SSRs
float duty_cycles[N];

//flags for message request packetization. 
bool done_writing_packets = true; // goes false when a request is made. 
String write_buffer[256]; // a write buffer which is an array of Strings, at most 256 elements long (very long message), each 32 bytes
int buffer_write_counter = 0;



int led = LED_BUILTIN;

void setup()
{
  pinMode(led, OUTPUT);
  //Wire1 comes from i2c driver library
  Wire1.begin(8);        // join i2c bus with address #8
  Wire1.onRequest(requestEvent); // register event
  Wire1.onReceive(receiveEvent); // register receive event
  Serial.begin(9600);
}

void loop()
{
  delay(100);
}


void createDataMessage()
{
  //temporarily generate random duty cycles, as this is simulated firmware
  for(int i=0; i < N; i++)
  {
    duty_cycles[i] = random(0, 100)/100.0;
  }
  String message = "A1:{"; //make whatever format you like. 
  for(int i=0; i < N; i++)
  {
    message += String(duty_cycles[i]);
    if(i != N-1)
    {
      message += ",";  
    }
  }
  message += "}";
  Serial.println(message);
  int buffer_counter = 0;
  for(int i = 0; i < message.length(); i+=31)
  {
    String substr;
    if(i+31 > message.length())
    {
      substr = message.substring(i);
    }
    else
    {
      substr = message.substring(i, i+31);
    }
    write_buffer[buffer_counter] = substr;
    buffer_counter += 1;
  }
  //end of message code
  write_buffer[buffer_counter] = "DEADBEEF";

}

//The node-red requests data from the arduino, but it can only
//get 32 bytes at a time. So, this requestEvent function is called
//for each 32 byte packet, but the packets themselves are buffered
//to include the SSR data until it "finishes" and sends an "end of message"
//byte code. At which point, global variables are switched to reform a new message
//at the next request. 
void requestEvent()
{
  digitalWrite(led, HIGH);      // briefly flash the LED
  //form message out of current duty cycles, with 0.0 representing "off" 

  //if this is the first time getting a request, packetize
  //new data to send out of a buffer. 
  if(done_writing_packets == true)
  {
    done_writing_packets = false;
    createDataMessage(); //stores message in a global variable
  }

  String message = write_buffer[buffer_write_counter];
  char mes[message.length()+1];
  message.toCharArray(mes, message.length()+1);
  buffer_write_counter += 1;
  
  Wire1.write(mes);    
  Serial.print("Sent: ");
  Serial.print(mes);
  Serial.println();
  digitalWrite(led, LOW);

  if(message == "DEADBEEF")
  {
    done_writing_packets = true;
    buffer_write_counter = 0;
  }
}

// function that executes whenever data is received from master
// this function is registered as an event, see setup()
void receiveEvent(int _)
{
  digitalWrite(led, HIGH);       // briefly flash the LED
  int count = 0;
  while(Wire1.available() > 0) {  // loop through all but the last
    char c = Wire1.read();        // receive byte as a character
    count += 1;
    Serial.print(c);             // print the character
  }
  Serial.print(": num bytes was ");
  Serial.println(count);             // print the integer
  digitalWrite(led, LOW);
}

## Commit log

2021-12-07 Delete WiDAQBoard-test.ino
    This was an old version of the Teensy code for the updated version look in the SSRTeensyCode folder.
2022-10-23 I went down a rabbit hole of attempting to pull the SSRController class out of the .ino file, due to some compiler errors I was having. That created more trouble, so I brought it back into the ino fi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
    [SSRTeensyCode.ino]
2022-10-23 See message from last commit. I just went through and double checked, I did already implement the Teensy_Slow_PWM initialization. Untested in this commit, but a similar implementation was tested in a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
2022-11-28 Added some documentation, still in progress, and added channel maps for different version of the PCB
2022-12-05 I've been exploring but not editing the firmware, as there is an issue with the heartbeat not returning real SSRController attributes. This commit acts as a starting point for me to make changes.
    [SSRTeensyCode.ino]
2023-06-07 This is the version that was actually used at FNAL to test 16 channels, as reported by Dylan. It will require an update of TeensyDuino core libraries for HardwareSerial in order to compile.
2023-06-07 Adding i2c tester code and a flows directory
2023-06-07 Added widaq-magis-ssr-v2b board files, all resources associated. Added readme to the i2c-tester directory
    [bom-12-15-22.xlsx, bom-2-21-22.xlsx, bom-3-30-22.xlsx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]
2023-06-13 fix the error temp used as the default PID ramp start temperature, since leaving it a large negative value can lead to a case where the PID loop thinks the current temperature is far below the setpoi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
    [SSRTeensyCode.ino]
